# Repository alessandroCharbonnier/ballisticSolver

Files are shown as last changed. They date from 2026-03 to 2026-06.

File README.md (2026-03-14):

# Ballistic Sentinel

A live ballistic calculator for long-range shooting, built on the ESP32-WROOM-32 platform.
The complete C++ ballistic engine is a from-scratch rewrite of [py_ballisticcalc](../bin/py_ballisticcalc),
validated to within 0.3% of the Python reference across 87 scenarios and 1850 trajectory points.

## Features

- **Pure C++ ballistic engine** — header-only library with adaptive RK45 Dormand-Prince integration (float inner loop on ESP32 hardware FPU, double position accumulation), PCHIP interpolation,
  CIPM-2007 atmosphere model, spin drift (Litz formula), Miller stability, Coriolis-ready (disabled pending magnetometer calibration)
- **All 9 standard drag tables**: G1, G7, G2, G5, G6, G8, GI, GS, RA4
- **Multi-BC support** — velocity-stepped ballistic coefficients
- **Four operating modes**:
  - **Live** — dial distance with a combination-lock style 4-digit display (yards)
  - **Staged** — pre-programmed target stages (PRS-style matches, up to 20)
  - **Sensor View** — real-time display of all sensor readings
  - **Digital Level** — full-screen cant readout with graphical bubble level, "LEVEL" indicator + display inversion when within sensitivity threshold, directional tilt hints when off-level
- **Real-time sensors** — BME280 (temperature/pressure/humidity), QMC5883P (compass heading), MPU6050 (cant/roll detection)
- **Calypso ultrasonic anemometer** — NMEA 0183 wind input (prepared, UART2)
- **Cant detection** — MPU6050 accelerometer with auto-calibration, visual cant slider, display auto-invert when level
- **SH1106 1.3" OLED** — 128×64 display with header, distance, corrections, sensor bar, scrolling menu with arrow indicators
- **5-way navigation button** — debounced with double-press, long-press (deep sleep), and auto-repeat
- **WiFi Access Point** — configure rifle/stages via a dark-themed web UI with captive portal
- **Persistent storage** — NVS for rifle config, stage definitions, and cant calibration
- **Power management** — auto-dim after 2 min inactivity (~80% brightness reduction), accelerometer-based auto deep-sleep after 10 min with no motion, ESP32 light sleep between sensor intervals, event-driven ballistic recalculation (on distance change only), BME280 forced mode, compass ODR reduced to 10 Hz, WiFi modem sleep when AP active
- **Battery monitoring** — LiPo voltage via ADC1 (GPIO36) with voltage divider, piecewise-linear discharge curve, battery icon in OLED header on all screens
- **Unit preferences** — configurable imperial/metric units for distance, velocity, weight, length, temperature, and pressure

## Hardware

### Bill of Materials

| Component | Part | Notes |
|---|---|---|
| MCU | ESP32-WROOM-32 (classic) | 520KB SRAM, 4MB Flash |
| Display | 1.3" OLED SH1106 I2C | 128×64, addr 0x3C |
| Env sensor | BME280 | Temp/press/humidity, addr 0x76 |
| Compass | QMC5883P (GY-271 module) | 3-axis magnetometer, addr 0x2C |
| Accelerometer | MPU6050 | Cant/roll detection, addr 0x68 |
| Button | 5-way digital navigation | One GPIO per direction + center |
| Wind sensor | Calypso ultrasonic (optional) | NMEA 0183 at 4800 baud |
| LED | On-board ESP32 LED | GPIO 2 |
| Battery | 3.7V LiPo (e.g. 2000mAh) | Requires 2× 100kΩ voltage divider |
| Resistors | 2 × 100kΩ | Voltage divider for battery ADC |

### Pin Map

| GPIO | Function | Direction | Notes |
|---|---|---|---|
| **21** | I2C SDA | Bidirectional | Shared bus: OLED + BME280 + QMC5883P + MPU6050 |
| **22** | I2C SCL | Output | 400 kHz Fast-mode |
| **32** | Button UP | Input (pull-up) | Active-low |
| **33** | Button DOWN | Input (pull-up) | Active-low |
| **25** | Button LEFT | Input (pull-up) | Active-low |
| **26** | Button RIGHT | Input (pull-up) | Active-low |
| **27** | Button CENTER | Input (pull-up) | Active-low, long-press (5s) = deep sleep, double-press = back |
| **16** | Wind UART2 RX | Input | ← Calypso TX (prepared) |
| **17** | Wind UART2 TX | Output | → Calypso RX (prepared) |
| **2** | Status LED | Output | Solid = WiFi AP active |
| **36** | Battery ADC (VP) | Input | Via 100kΩ+100kΩ voltage divider, ADC1_CH0 |

### I2C Bus Addresses

| Address | Device | Protocol |
|---|---|---|
| 0x3C | SH1106 OLED | U8g2 HW I2C |
| 0x76 | BME280 | Adafruit BME280 |
| 0x2C | QMC5883P | 3-axis magnetometer |
| 0x68 | MPU6050 | Adafruit MPU6050 |

### Wiring Diagram

```
ESP32-WROOM-32
├── GPIO 21 (SDA) ──┬── OLED SDA
│                    ├── BME280 SDA
│                    ├── QMC5883P SDA
│                    └── MPU6050 SDA
├── GPIO 22 (SCL) ──┬── OLED SCL
│                    ├── BME280 SCL
│                    ├── QMC5883P SCL
│                    └── MPU6050 SCL
├── GPIO 32 ──── BTN UP
├── GPIO 33 ──── BTN DOWN
├── GPIO 25 ──── BTN LEFT
├── GPIO 26 ──── BTN RIGHT
├── GPIO 27 ──── BTN CENTER
├── GPIO 16 ──── Calypso TX (RX2)
├── GPIO 17 ──── Calypso RX (TX2)
├── GPIO 36 (VP) ── Battery voltage divider mid-point
│                    (Batt+ ─[100kΩ]─ GPIO36 ─[100kΩ]─ GND)
└── GPIO  2 ──── On-board LED
```

## Software Architecture

```
Ballistic Sentinel/
├── lib/ballistic/          # Header-only C++ ballistic library
│   ├── ballistic.h         # Umbrella include
│   ├── constants.h         # Physical constants, unit conversions
│   ├── vector3d.h          # 3D vector math (Vector3 double + Vector3f float)
│   ├── drag_tables.h       # 9 drag tables (G1/G7/G2/G5/G6/G8/GI/GS/RA4)
│   ├── interpolation.h     # PCHIP Fritsch-Carlson spline
│   ├── atmosphere.h        # CIPM-2007 air density model
│   ├── drag_model.h        # Single & multi-BC drag models
│   ├── trajectory.h        # TrajectoryPoint, CorrectionResult
│   ├── engine_rk4.h        # RK45 Dormand-Prince adaptive integrator, Ridder zero-finding
│   └── calculator.h        # High-level API
├── src/                    # ESP32 firmware
│   ├── config.h            # Pin assignments, timing constants
│   ├── display.h/.cpp      # U8g2 SH1106 OLED driver
│   ├── input.h/.cpp        # 5-way button with debounce/repeat
│   ├── sensors.h/.cpp      # BME280 + QMC5883P + MPU6050 polling
│   ├── storage.h/.cpp      # NVS persistent config
│   ├── web_ui.h            # PROGMEM HTML/CSS/JS
│   ├── webserver.h/.cpp    # ESPAsyncWebServer REST API
│   ├── wind.h/.cpp         # Calypso NMEA parser
│   ├── modes.h/.cpp        # Live/Staged/Sensor mode manager
│   └── main.cpp            # Firmware entry point
├── test/
│   ├── test_native/        # Unity C++ unit tests (37 cases)
│   └── test_compare/       # C++ output for Python comparison
└── platformio.ini          # Build configuration
```

### Ballistic Library API

```cpp
#include <ballistic.h>
using namespace ballistic;

Calculator calc;
calc.configure(0.315, DragTableId::G7,  // BC, drag table
               140, 0.264, 1.35,        // weight_gr, diameter_in, length_in
               2710, 1.5, 8.0, 100);    // mv_fps, sight_in, twist_in, zero_yd
calc.setAtmosphere(59.0, 29.92, 0.0);   // temp_F, pressure_inHg, humidity 0-1
calc.setWind(10.0, 90.0);               // speed_fps, direction_deg
calc.solve();                            // find zero elevation

auto corr = calc.correction(800);        // at 800 yards
// corr.vertical, corr.horizontal, corr.velocity_fps, etc.

auto traj = calc.trajectory(2000, 100);  // max range, step (yards)
for (auto& pt : traj) {
    // pt.distance_ft, pt.height_ft, pt.velocity_fps, pt.mach, ...
}
```

## Building

### Prerequisites

- [PlatformIO CLI](https://platformio.org/install/cli)
- ESP32 board support (auto-installed by PlatformIO)

### Flash Firmware

```bash
cd "Ballistic Sentinel"
pio run -e upesy_wroom -t upload
```

### Run Native Tests

```bash
cd "Ballistic Sentinel"
pio test -e native
```

Expected: **37/37 PASS**

### Run Comparison Tests

Requires `py_ballisticcalc` installed in a Python environment and `g++` in PATH:

```bash
cd <project_root>
python tests/test_compare.py
```

Expected: **1850/1850 PASS** (87 scenarios across 8 calibers, multiple bullets/conditions/features)

## Performance Optimizations

The ESP32 Xtensa LX6 has a hardware single-precision (float) FPU but emulates all double-precision operations in software (~10–50× slower per operation). The ballistic engine is optimized for this constraint:

| Optimization | Description |
|---|---|
| **Float inner loop** | All RK45 velocity/acceleration/k-stage math uses `Vector3f` (float) on hardware FPU. Position accumulation stays in `Vector3` (double) to prevent systematic drift. `sqrtf(sqrtf(x))` replaces `pow(x, 0.25)` for step rejection. |
| **Adaptive RK45 Dormand-Prince** | Replaces fixed-step RK4. Auto-sizes dt from 0.0005s–0.02s based on local truncation error. Large steps in smooth supersonic flight, small steps near transonic. ~3–5× fewer steps than fixed-step at long range. |
| **Atmosphere amortization** | Atmospheric density and speed-of-sound recalculated every 8 steps instead of every step (~87% reduction in CIPM-2007 overhead). |
| **Reciprocal Mach pre-compute** | `1.0/mach_local` computed once per atmosphere refresh, used as multiplication in all 6–7 RK stages per step. |
| **Polynomial barometric formula** | 5th-order Horner's polynomial replaces `std::pow()` in altitude lookup. |
| **Dry-air density fast path** | `cipmDensity()` skips `exp()` and water vapor math when humidity = 0 (the default). |
| **Hinted spline evaluation** | `PchipSpline::evalHinted()` with O(1) amortized lookups instead of O(log n) binary search. |

### Double-Precision Fallback

To revert all integration loops to double precision (for accuracy comparison or debugging), add to `platformio.ini`:

```ini
build_flags =
    -DUSE_DOUBLE_INNER_LOOP
    ...
```

## Web Interface

1. Select **WiFi Toggle** from the main menu to start WiFi AP
2. Connect to **BallisticSentinel** (password: `longrange`)
3. Open `http://192.168.4.1` in any browser (captive portal auto-redirects)
4. Configure rifle parameters, unit preferences, and stage targets
5. Select **WiFi Toggle** again to turn off WiFi

The web UI uses a dark theme (`#0d1117` background) with green accents (`#16c79a`)
and a Courier New monospace font. Includes unit conversion (imperial/metric),
multi-BC configuration, powder sensitivity calculator, cant calibration, and
correction unit selection (MOA, SMOA, MRAD, CM, CLICKS).

### API Endpoints

| Method | Path | Description |
|---|---|---|
| GET | `/` | Web configuration UI |
| GET | `/api/config` | Current rifle + stage config (JSON) |
| POST | `/api/save` | Save rifle + stage config |
| POST | `/api/wifi/off` | Shut down WiFi AP |
| POST | `/api/cant/calibrate` | Start cant auto-calibration |

## Test Coverage

### Native C++ Tests (37 cases)

| Group | Tests | Description |
|---|---|---|
| Constants | 3 | Gravity, std atmosphere, unit conversions |
| Vector3 | 5 | Addition, magnitude, normalize, scalar, dot |
| PCHIP | 2 | Basic interpolation, G7 table accuracy |
| Atmosphere | 5 | Standard, hot, altitude, humidity, unit conversion |
| Drag Model | 2 | Single BC, all 9 tables exist |
| Zero-Finding | 2 | 100 yd, 200 yd zero |
| Trajectory | 3 | Drop increases, velocity decreases, reasonable values |
| Calibers | 4 | .308 G7, .338LM G7, .50BMG G1, 6mm CM G7 |
| Weather | 2 | Hot vs cold, altitude effect |
| Wind | 2 | Crosswind deflection, no-wind spin drift |
| Coriolis | 1 | Effect at 2000 yd |
| Corrections | 2 | MOA/MRAD consistency, click calculations |
| Advanced | 2 | Powder sensitivity, multi-BC |
| Edge Cases | 2 | Zero-distance correction, very close range |

### Python Comparison (1850 points, 87 scenarios)

| Category | Scenarios | Drag | Range | Notes |
|---|---|---|---|---|
| .22 LR brands | 12 | RA4 | 300 yd | SK, Eley Tenex, Eley ELR, Lapua (Center-X, Midas+, LR, SLR, X-Act), RWS R50, CCI SV, Federal GMT |
| .22 LR weather | 5 | RA4 | 300 yd | Hot, cold, altitude, tropical, desert |
| .22 LR wind | 4 | RA4 | 300 yd | 5/10/15 mph cross, quartering |
| .22 LR K22 combo | 1 | RA4 | 300 yd | Hot + crosswind (King of 22LR match day) |
| 6.5 CM bullets | 6 | G7 | 1200 yd | Berger 140 HT, Sierra 140 SMK, Hornady 147 ELD-M + 3 handloads |
| 6.5 CM conditions | 5 | G7 | 1200 yd | Wind, hot, cold, altitude, PRS combined |
| 6mm CM bullets | 4 | G7 | 1200 yd | A-Tip 110, Berger 105 HT, Berger 115 DTAC handload, wind |
| .308 Win bullets | 6 | G7 | 1200 yd | ELD-M 168/178, Berger 185 Jugg, 200gr handload, wind, hot |
| .338 LM (K1M) | 5 | G7 | 1760 yd | ELD-M 285, Berger 300, CE 275, handload, K1M combo |
| .300 PRC (K1M) | 3 | G7 | 1760 yd | A-Tip 250, Berger 230 handload, K1M combo |
| .375 CT (K2M) | 4 | G7 | 3520 yd | 350gr, CE 377, handload, K2M alt+wind |
| .50 BMG (ELR) | 3 | G1 | 2500–3520 yd | Wind, altitude, K2M range |
| Extreme weather | 4 | G7 | 1200–1760 yd | Desert 110°F, mountain 8500 ft, tropical, 7500 ft |
| Wind angles | 5 | G7 | 1200 yd | Head/tail/quartering 45°/135°, 20 mph gust |
| Multi-BC | 6 | G7 | 1200–1760 yd | Velocity-stepped BCs: 6.5 CM, 6mm CM, .308, .338 LM, .300 PRC (with wind/altitude) |
| Powder sensitivity | 6 | G7 | 1200–1760 yd | MV adjusted for temp: cold/hot across 6.5 CM, .308, .338 LM, .300 PRC (with wind/altitude) |
| Original baseline | 8 | G1/G7 | 1500–3000 yd | Original 8 scenarios retained |

**Competition distances**: King of 22LR (300 yd), PRS (1200 yd), King of 1 Mile (1760 yd), King of 2 Miles (3520 yd)

Tolerance: max(0.65"/500yd × distance, 0.3% of absolute value)

## Ideas

**Areas for Improvement**

- Single rifle profile only — serious limitation; PRS shooters switch rifles/loads between stages or seasons
- Wind: manual speed + direction only — oversimplified; no crosswind component decomposition shown to user
- Calypso anemometer: prepared but not connected — the most valuable sensor for the use case is the one that doesn't work yet
- WiFi AP hardcoded credentials — SSID "BallisticSentinel" / password "longrange"; anyone at the range can connect and modify config
- 128×64 monochrome OLED — barely enough pixels for a ballistic HUD; hard to read in bright sun. Acceptable for V1 but limiting
- No shot logging / history — can't review previous shots, stages, or environmental conditions after the fact
- No BLE support — BLE would enable Kestrel data link and phone app integration with far less power than WiFi
- Stage names limited to 16 chars — "Stage 3 - 487yd Barricade" doesn't fit; minor but annoying for match prep
- No truing / velocity validation — no way to true the BC or MV from observed impacts; experienced shooters rely on this heavily
- Latitude set manually via web UI — should auto-populate from phone GPS via the web interface

### Potential Features

#### Ballistic Engine Accuracy

These features address the real-world error budget identified via physics audit and Doppler radar field data (Lapua, Applied Ballistics). Ordered by impact on accuracy.

| Priority | Feature | Impact | Rationale |
|---|---|---|---|
| 1 | **Custom Cd vs Mach drag tables** | Eliminates 1–3+ mil ELR error | G7/G1 are reference-shape approximations. Real bullets have unique drag curves, especially in transonic (Mach 0.9–1.2). Applied Ballistics and Lapua publish Doppler-measured Cd tables. Infrastructure already exists — `PchipSpline` + `DragModel` just need a raw `(Mach, Cd)` constructor that bypasses reference table + BC division. Single highest-impact accuracy improvement possible. |
| 2 | **BC/MV truing from observed impacts** | ~0.3–1 mil at all ranges | Manufacturer BCs can be off 3–5%. MV varies lot-to-lot. Truing adjusts BC and/or MV to match actual observed drop at a known distance. Every serious ballistic app (AB, Kestrel, Strelok) has this. Without it, there's no closed-loop correction. |
| 3 | **Humidity correction to speed of sound** | ~0.05 mil at ELR | Current Mach calculation uses dry-air ideal gas (`sqrt(T_R) × 49.0223`). At 35°C/100% RH, humid air transmits sound ~1.5 m/s faster (0.44% shift). This shifts the transonic boundary and Cd lookup. Low effort — adjust `mach_fps` using water vapor mole fraction already computed by CIPM-2007. |
| 4 | **Aerodynamic jump correction** | ~0.1–0.3 MOA crosswind | When a crosswind acts on a spinning bullet at launch, gyroscopic precession deflects it vertically (up or down depending on twist direction and wind side). Currently ignored. Formula: `AJ ≈ (2 * Clα * ρ * S * d * p) / (2 * m * V) * wind_cross`. Matters at ELR and in strong crosswind. |
| 5 | **Drag table blending / transonic Cd override** | Reduces transonic uncertainty | Allow users to override specific Mach regions of the drag table (e.g., Mach 0.9–1.2) with measured data while keeping G7 elsewhere. Useful for shooters who have partial Doppler data or truing data at transonic distances. |

#### Device & UX Features

| Priority | Feature | Rationale |
|---|---|---|
| 1 | Multiple rifle/load profiles | Hobby shooters often own 3–10 rifles. Switching profiles must be trivial. |
| 2 | Timer in live / staged | Pressing on timer icon starts a countdown, configurable on device or via web app. |
| 2 | GPS integration (phone → device) | Auto-populate latitude, altitude, and azimuth. Removes manual entry errors for Coriolis. |
| 3 | Wind sensor activation (Calypso or Kestrel link) | Measured wind >> guessed wind. Finish the Calypso UART or add Kestrel BLE link. |
| 4 | Azimuth-aware wind decomposition | Show headwind/crosswind components relative to shot direction, not just raw wind angle. Helps shooters visualize the actual correction. |
| 5 | Come-up card / range table export | Many hobbyists tape a card to their stock. Web UI "print range card" is the killer feature for casual use. |
| 6 | Rangefinder BLE integration | Nice-to-have for practice sessions; not needed for competition (Stage mode covers it). |
| 7 | Larger display or e-ink option | Hobbyists shoot in bright sun at benches. E-ink is sunlight-readable and ultra-low power. |
| 8 | Unit conversion calculator | Quick MOA↔MRAD, yards↔meters, fps↔m/s. Hobbyists constantly convert between systems. |
| 9 | BLE phone app | Richer UI for config, real-time mirroring, shot log export, GPS feed — all over low-power BLE. |
| 10 | OTA firmware updates | Hobby users won't flash firmware via USB. WiFi OTA update from web UI is essential for adoption. |
| 11 | Onboard tutorial / help screens | Brief "how to use" on first boot or from menu. Reduces learning curve. |
| 12 | Target angular size / mil-ranging | Calculate target size in mils for rangefinder-less verification or unknown-distance stages (UKD). |
| 13 | Bullet library / presets | Built-in database of common bullets (Sierra, Hornady, Berger) with BC + dimensions pre-filled. Huge time saver. |
| 14 | Shot logging / history | Record shot conditions, corrections, and results for post-session review and trend analysis. |
| 15 | ~~double precision~~ | ✅ Implemented — add `-DUSE_DOUBLE_INNER_LOOP` to `build_flags` in `platformio.ini` to revert all integration loops from float to double precision |

#### Not Worth Implementing (diminishing returns)

| Feature | Why not | Actual impact |
|---|---|---|
| 6DOF model | Requires bullet-specific aerodynamic coefficients (Clα, Cmα, Cnpα, etc.) that shooters don't have. Without them, 6DOF is no better than 3DOF. | ~0.2 mil at 2,700m — dwarfed by transonic drag uncertainty |
| Improved spin drift model | Litz formula is ~10–20% approximate, but spin drift itself is small at PRS ranges. Proper modeling requires 6DOF. | ~0.04 MOA at PRS, ~0.2–0.5 MOA at ELR |
| Altitude-dependent gravity | $g$ varies by ~0.3% from sea level to 10,000 ft. | < 0.01 mil even at ELR |
| Earth curvature correction | Drop-away of ~8" per mile². | ~0.02 mil at 2,000 yd, negligible at PRS |
| Adaptive RK4 step size | Current fixed dt=0.0025s is already accurate to < 0.01 mil. | No measurable improvement |

## Version History

| Version | Date | Changes |
|---|---|---|
| 1.0.0 | 2025-01-XX | Initial release — complete C++ ballistic engine, ESP32 firmware, web UI, 37 native tests, 173-point Python comparison |
| 1.1.0 | 2026-03-13 | Power optimization: event-driven ballistic calc, BME280 forced mode, compass 10 Hz ODR, display 4 fps, split sensor intervals (cant 5 Hz / env 0.5 Hz), ESP32 light sleep, WiFi modem sleep, auto-dim (2 min / 80%), accelerometer-based auto deep-sleep (10 min / 0.43g threshold). Bug fixes: deep-sleep GPIO wakeup loop, wake-from-sleep phantom button press, display inversion persisting on shutdown/wake screens |
| 1.2.0 | 2026-03-13 | New Digital Level mode with full-screen cant readout, graphical bubble level, sensitivity zone marks, "LEVEL" indicator with display inversion, and directional tilt hints. Scrolling main menu with up/down arrow indicators (supports 5+ items without shrinking text). WiFi toggle moved to last menu position |
| 1.3.0 | 2026-03-14 | Expanded comparison test suite: 75 scenarios / 1578 trajectory points (up from 8 / 173). Added .22 LR competition bullets (12 brands, RA4 drag table), centerfire competition & handloaded profiles across 6.5 CM, 6mm CM, .308 Win, .338 LM, .300 PRC, .375 CT, .50 BMG. Weather matrix (hot/cold/altitude/tropical/desert/mountain), wind angles (head/tail/quartering/gust), and competition distance ranges (King of 22LR, PRS, King of 1 Mile, King of 2 Miles) |
| 1.4.0 | 2026-03-14 | Added multi-BC and powder sensitivity comparison scenarios (12 new, 87 total / 1850 points). 6 multi-BC scenarios with velocity-stepped BCs across 5 calibers. 6 powder sensitivity scenarios testing MV adjustment for cold/hot conditions. Both features now validated in C++ vs Python comparison suite |

## License

Internal project — not for distribution.

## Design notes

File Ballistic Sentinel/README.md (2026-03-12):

# Ballistic Sentinel

A live ballistic calculator for long-range shooting, built on the ESP32-WROOM-32 platform.
The complete C++ ballistic engine is a from-scratch rewrite of [py_ballisticcalc](../bin/py_ballisticcalc),
validated to within 0.25% of the Python reference across 8 scenarios and 173 trajectory points.

## Features

- **Pure C++ ballistic engine** — header-only library with RK4 integration, PCHIP interpolation,
  CIPM-2007 atmosphere model, full 3D Coriolis, spin drift (Litz formula), Miller stability
- **All 9 standard drag tables**: G1, G7, G2, G5, G6, G8, GI, GS, RA4
- **Multi-BC support** — velocity-stepped ballistic coefficients
- **Two shooting modes**:
  - **Live** — dial distance with a combination-lock style 4-digit display (yards)
  - **Staged** — pre-programmed target stages (PRS-style matches, up to 20)
- **Real-time sensors** — BME280 (temperature/pressure/humidity), QMC5883L (compass heading for Coriolis)
- **Calypso ultrasonic anemometer** — NMEA 0183 wind input (prepared, UART2)
- **SH1106 1.3" OLED** — 128×64 display with header, distance, corrections, sensor bar
- **5-way navigation button** — debounced with long-press and auto-repeat
- **WiFi Access Point** — configure rifle/stages via a dark-themed web UI
- **Persistent storage** — NVS for rifle config and stage definitions
- **Preset calibers** — 6.5CM, 6CM, 6.5PRC, .308, .300WM, .300PRC, .338LM, .375CT, .50BMG

## Hardware

### Bill of Materials

| Component | Part | Notes |
|---|---|---|
| MCU | ESP32-WROOM-32 (classic) | 520KB SRAM, 4MB Flash |
| Display | 1.3" OLED SH1106 I2C | 128×64, addr 0x3C |
| Env sensor | BME280 | Temp/press/humidity, addr 0x76 |
| Compass | QMC5883L (GY-271 module) | 3-axis magnetometer, addr 0x0D |
| Button | 5-way digital navigation | One GPIO per direction + center |
| Wind sensor | Calypso ultrasonic (optional) | NMEA 0183 at 4800 baud |
| LED | On-board ESP32 LED | GPIO 2 |

### Pin Map

| GPIO | Function | Direction | Notes |
|---|---|---|---|
| **21** | I2C SDA | Bidirectional | Shared bus: OLED + BME280 + QMC5883L |
| **22** | I2C SCL | Output | 400 kHz Fast-mode |
| **32** | Button UP | Input (pull-up) | Active-low |
| **33** | Button DOWN | Input (pull-up) | Active-low |
| **25** | Button LEFT | Input (pull-up) | Active-low |
| **26** | Button RIGHT | Input (pull-up) | Active-low |
| **27** | Button CENTER | Input (pull-up) | Active-low, long-press = WiFi toggle |
| **16** | Wind UART2 RX | Input | ← Calypso TX (prepared) |
| **17** | Wind UART2 TX | Output | → Calypso RX (prepared) |
| **2** | Status LED | Output | Solid = WiFi AP active |

### I2C Bus Addresses

| Address | Device | Protocol |
|---|---|---|
| 0x3C | SH1106 OLED | U8g2 HW I2C |
| 0x76 | BME280 | Adafruit BME280 |
| 0x0D | QMC5883L | QMC5883LCompass |

### Wiring Diagram

```
ESP32-WROOM-32
├── GPIO 21 (SDA) ──┬── OLED SDA
│                    ├── BME280 SDA
│                    └── QMC5883L SDA
├── GPIO 22 (SCL) ──┬── OLED SCL
│                    ├── BME280 SCL
│                    └── QMC5883L SCL
├── GPIO 32 ──── BTN UP
├── GPIO 33 ──── BTN DOWN
├── GPIO 25 ──── BTN LEFT
├── GPIO 26 ──── BTN RIGHT
├── GPIO 27 ──── BTN CENTER
├── GPIO 16 ──── Calypso TX (RX2)
├── GPIO 17 ──── Calypso RX (TX2)
└── GPIO  2 ──── On-board LED
```

## Software Architecture

```
Ballistic Sentinel/
├── lib/ballistic/          # Header-only C++ ballistic library
│   ├── ballistic.h         # Umbrella include
│   ├── constants.h         # Physical constants, unit conversions
│   ├── vector3d.h          # 3D vector math
│   ├── drag_tables.h       # 9 drag tables (G1/G7/G2/G5/G6/G8/GI/GS/RA4)
│   ├── interpolation.h     # PCHIP Fritsch-Carlson spline
│   ├── atmosphere.h        # CIPM-2007 air density model
│   ├── drag_model.h        # Single & multi-BC drag models
│   ├── trajectory.h        # TrajectoryPoint, CorrectionResult
│   ├── engine_rk4.h        # RK4 integration engine, Ridder zero-finding
│   └── calculator.h        # High-level API
├── src/                    # ESP32 firmware
│   ├── config.h            # Pin assignments, timing constants
│   ├── display.h/.cpp      # U8g2 SH1106 OLED driver
│   ├── input.h/.cpp        # 5-way button with debounce/repeat
│   ├── sensors.h/.cpp      # BME280 + QMC5883L polling
│   ├── storage.h/.cpp      # NVS persistent config
│   ├── web_ui.h            # PROGMEM HTML/CSS/JS
│   ├── webserver.h/.cpp    # ESPAsyncWebServer REST API
│   ├── wind.h/.cpp         # Calypso NMEA parser
│   ├── modes.h/.cpp        # Live/Staged mode manager
│   └── main.cpp            # Firmware entry point
├── test/
│   ├── test_native/        # Unity C++ unit tests (37 cases)
│   └── test_compare/       # C++ output for Python comparison
└── platformio.ini          # Build configuration
```

### Ballistic Library API

```cpp
#include <ballistic.h>
using namespace ballistic;

Calculator calc;
calc.configure(0.315, DragTableId::G7,  // BC, drag table
               140, 0.264, 1.35,        // weight_gr, diameter_in, length_in
               2710, 1.5, 8.0, 100);    // mv_fps, sight_in, twist_in, zero_yd
calc.setAtmosphere(59.0, 29.92, 0.0);   // temp_F, pressure_inHg, humidity 0-1
calc.setWind(10.0, 90.0);               // speed_fps, direction_deg
calc.solve();                            // find zero elevation

auto corr = calc.correction(800);        // at 800 yards
// corr.elevation_moa, corr.windage_moa, corr.velocity_fps, etc.

auto traj = calc.trajectory(2000, 100);  // max range, step (yards)
for (auto& pt : traj) {
    // pt.distance_ft, pt.height_ft, pt.velocity_fps, pt.mach, ...
}
```

## Building

### Prerequisites

- [PlatformIO CLI](https://platformio.org/install/cli)
- ESP32 board support (auto-installed by PlatformIO)

### Flash Firmware

```bash
cd "Ballistic Sentinel"
pio run -e upesy_wroom -t upload
```

### Run Native Tests

```bash
cd "Ballistic Sentinel"
pio test -e native
```

Expected: **37/37 PASS**

### Run Comparison Tests

Requires `py_ballisticcalc` installed in a Python environment and `g++` in PATH:

```bash
cd <project_root>
python tests/test_compare.py
```

Expected: **173/173 PASS** (8 scenarios × up to 31 points each)

## Web Interface

1. Long-press CENTER button (3s) to start WiFi AP
2. Connect to **BallisticSentinel** (password: `longrange`)
3. Open `http://192.168.4.1` in any browser
4. Configure rifle parameters and stage targets
5. Long-press CENTER again to turn off WiFi

The web UI uses a dark theme (`#0d1117` background) with green accents (`#16c79a`)
and a monospace font. Includes preset caliber buttons for quick setup.

### API Endpoints

| Method | Path | Description |
|---|---|---|
| GET | `/` | Web configuration UI |
| GET | `/api/config` | Current rifle + stage config (JSON) |
| POST | `/api/save` | Save rifle + stage config |
| POST | `/api/wifi/off` | Shut down WiFi AP |

## Test Coverage

### Native C++ Tests (37 cases)

| Group | Tests | Description |
|---|---|---|
| Constants | 3 | Gravity, std atmosphere, unit conversions |
| Vector3 | 5 | Addition, magnitude, normalize, scalar, dot |
| PCHIP | 2 | Basic interpolation, G7 table accuracy |
| Atmosphere | 5 | Standard, hot, altitude, humidity, unit conversion |
| Drag Model | 2 | Single BC, all 9 tables exist |
| Zero-Finding | 2 | 100 yd, 200 yd zero |
| Trajectory | 3 | Drop increases, velocity decreases, reasonable values |
| Calibers | 4 | .308 G7, .338LM G7, .50BMG G1, 6mm CM G7 |
| Weather | 2 | Hot vs cold, altitude effect |
| Wind | 2 | Crosswind deflection, no-wind spin drift |
| Coriolis | 1 | Effect at 2000 yd |
| Corrections | 2 | MOA/MRAD consistency, click calculations |
| Advanced | 2 | Powder sensitivity, multi-BC |
| Edge Cases | 2 | Zero-distance correction, very close range |

### Python Comparison (173 points, 8 scenarios)

| Scenario | Drag | Range | Conditions |
|---|---|---|---|
| 6.5 Creedmoor | G7 | 2000 yd | Standard atmosphere |
| .308 Winchester | G7 | 1500 yd | 10 mph crosswind |
| .338 Lapua Magnum | G7 | 2500 yd | Hot (100°F), humid |
| .50 BMG | G1 | 2500 yd | Standard atmosphere |
| 6mm Creedmoor | G7 | 1500 yd | Cold (20°F) |
| .300 PRC | G7 | 2000 yd | High altitude (≈5000 ft) |
| .308 Winchester | G1 | 1500 yd | G1 reference |
| .375 CheyTac | G7 | 3000 yd | Extreme long range |

Tolerance: max(0.5"/500yd × distance, 0.25% of absolute value)

## Version History

| Version | Date | Changes |
|---|---|---|
| 1.0.0 | 2025-01-XX | Initial release — complete C++ ballistic engine, ESP32 firmware, web UI, 37 native tests, 173-point Python comparison |

## License

Internal project — not for distribution.

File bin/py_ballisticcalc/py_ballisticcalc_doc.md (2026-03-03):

# py_ballisticcalc Documentation (v2.2.8)

Ballistic trajectory calculator library for Python.  
`pip install py-ballisticcalc`

---

## Table of Contents

1. [Quick Start](#quick-start)
2. [Units System](#units-system)
3. [Core Classes](#core-classes)
   - [DragModel](#dragmodel)
   - [DragModelMultiBC / BCPoint](#dragmodelmultibc--bcpoint)
   - [Ammo](#ammo)
   - [Weapon](#weapon)
   - [Sight](#sight)
   - [Atmo](#atmo)
   - [Wind](#wind)
   - [Shot](#shot)
   - [Calculator](#calculator)
4. [Results](#results)
   - [HitResult](#hitresult)
   - [TrajectoryData](#trajectorydata)
   - [DangerSpace](#dangerspace)
   - [TrajFlag](#trajflag)
5. [Unit Reference](#unit-reference)
   - [Distance](#distance)
   - [Velocity](#velocity)
   - [Angular](#angular)
   - [Weight](#weight)
   - [Temperature](#temperature)
   - [Pressure](#pressure)
   - [Energy](#energy)
6. [PreferredUnits](#preferredunits)
7. [Integration Engines](#integration-engines)
8. [Utility Functions](#utility-functions)

---

## Quick Start

```python
from py_ballisticcalc import *
from py_ballisticcalc.unit import *

# 1. Define drag model
dm = DragModel(0.223, TableG7, Weight(175, Weight.Grain), Distance(0.308, Distance.Inch))

# 2. Define ammo
ammo = Ammo(dm, Velocity(2700, Velocity.FPS))

# 3. Define atmosphere
atmo = Atmo(
    altitude=Distance(0, Distance.Foot),
    pressure=Pressure(29.92, Pressure.InHg),
    temperature=Temperature(59, Temperature.Fahrenheit),
    humidity=0.5
)

# 4. Define weapon
weapon = Weapon(sight_height=Distance(1.5, Distance.Inch), twist=Distance(10, Distance.Inch))

# 5. Define wind
wind = [Wind(Velocity(5, Velocity.MPS), Angular(90, Angular.Degree))]

# 6. Build shot and calculate
shot = Shot(weapon=weapon, ammo=ammo, atmo=atmo, winds=wind)
calc = Calculator()
calc.set_weapon_zero(shot, Distance(100, Distance.Yard))

results = calc.fire(shot,
                    trajectory_range=Distance(1000, Distance.Yard),
                    trajectory_step=Distance(100, Distance.Yard))

# 7. Read results
for p in results:
    print(p.distance >> Distance.Yard,
          p.height >> Distance.Inch,
          p.drop_angle >> Angular.MRad,
          p.windage >> Distance.Inch,
          p.velocity >> Velocity.FPS)
```

---

## Units System

All measurement values are wrapped in typed dimension classes. Each class stores values internally in a **raw unit** and converts on demand.

### Creating a value

```python
d = Distance(100, Distance.Meter)      # constructor
d = Distance.Meter(100)                # not available for all — use constructor form
```

### Reading a value

```python
# >> operator (get_in shorthand)
meters = d >> Distance.Meter           # returns float

# .get_in() method
yards = d.get_in(Distance.Yard)        # returns float

# .convert() — returns new object in different units
d2 = d.convert(Distance.Yard)          # Distance object in yards

# << operator — returns new object without mutating
d3 = d << Distance.Foot                # new Distance in feet, d unchanged
```

### Properties

| Property | Description |
|---|---|
| `.raw_value` | Internal value in the dimension's base unit |
| `.unit_value`| Value in the units it was created with |
| `.units` | The Unit enum it was created with |

### Arithmetic

Unit objects support `+`, `-`, `*`, `/` with numbers and same-dimension objects.  
Dividing two same-dimension objects returns a `float` ratio.  
**Temperature** only supports `+` and `-` (clamped at absolute zero).

---

## Core Classes

### DragModel

Aerodynamic drag model for a projectile.

```python
DragModel(
    bc: float,                    # Ballistic coefficient
    drag_table: list,             # Standard table (TableG1, TableG7, TableRA4, etc.)
    weight: float | Weight = 0,   # Bullet weight (grains) — needed for spin drift
    diameter: float | Distance = 0, # Bullet diameter (inches) — needed for spin drift
    length: float | Distance = 0   # Bullet length (inches) — needed for spin drift
)
```

**Available drag tables:** `TableG1`, `TableG2`, `TableG5`, `TableG6`, `TableG7`, `TableG8`, `TableGI`, `TableGS`, `TableRA4`

Use `get_drag_tables_names()` to list them all at runtime.

**Attributes:**
- `BC` — Ballistic coefficient
- `drag_table` — List of `DragDataPoint(Mach, CD)` pairs
- `weight`, `diameter`, `length` — Projectile dimensions
- `sectional_density` — Calculated lb/in²
- `form_factor` — Calculated dimensionless form factor

**Custom drag table:**
```python
dm = DragModel(1, [DragDataPoint(1, 0.3)])  # Constant Cd = 0.3
```

---

### DragModelMultiBC / BCPoint

Create a drag model from multiple BCs at different velocities. The library interpolates between them.

```python
DragModelMultiBC(
    bc_points: list[BCPoint],
    drag_table: list,
    weight: float | Weight = 0,
    diameter: float | Distance = 0,
    length: float | Distance = 0
) -> DragModel
```

**BCPoint:**
```python
BCPoint(BC: float, Mach: float | None = None, V: float | Velocity | None = None)
```
Specify **either** `Mach` or `V`, not both. Points are auto-sorted by Mach number.

**Example:**
```python
dm = DragModelMultiBC(
    bc_points=[
        BCPoint(BC=0.22, V=Velocity(2500, Velocity.FPS)),
        BCPoint(BC=0.21, V=Velocity(1500, Velocity.FPS)),
    ],
    drag_table=TableG7,
    weight=Weight(175, Weight.Grain),
    diameter=Distance(0.308, Distance.Inch),
)
```

---

### Ammo

Ammunition configuration.

```python
Ammo(
    dm: DragModel,
    mv: float | Velocity,                     # Muzzle velocity
    powder_temp: float | Temperature = None,   # Baseline powder temp (default 15°C)
    temp_modifier: float = 0,                  # Velocity change % per 15°C
    use_powder_sensitivity: bool = False        # Enable auto velocity adjustment
)
```

**Methods:**

| Method | Description |
|---|---|
| `calc_powder_sens(other_velocity, other_temperature)` | Calculate temp sensitivity from two data points. Sets `temp_modifier`. Returns the modifier. |
| `get_velocity_for_temp(current_temp)` | Get temperature-adjusted muzzle velocity. Returns baseline velocity if `use_powder_sensitivity=False`. |

**Powder sensitivity example:**
```python
ammo = Ammo(dm, Velocity(815, Velocity.MPS),
            powder_temp=Temperature(15, Temperature.Celsius),
            use_powder_sensitivity=True)
ammo.calc_powder_sens(Velocity(830, Velocity.MPS), Temperature(30, Temperature.Celsius))
cold_vel = ammo.get_velocity_for_temp(Temperature(-10, Temperature.Celsius))
```

---

### Weapon

Weapon/sight configuration.

```python
Weapon(
    sight_height: float | Distance = None,     # Sight above bore (at muzzle)
    twist: float | Distance = None,            # Barrel twist (+ = right-hand)
    zero_elevation: float | Angular = None,    # Set by Calculator.set_weapon_zero()
    sight: Sight = None                        # Optional sight configuration
)
```

---

### Sight

Optical sight configuration for click calculations.

```python
Sight(
    focal_plane: Literal['FFP', 'SFP', 'LWIR'] = 'FFP',
    scale_factor: float | Distance = None,     # Required for SFP
    h_click_size: float | Angular = None,      # Horizontal click size
    v_click_size: float | Angular = None       # Vertical click size
)
```

**Methods:**

| Method | Description |
|---|---|
| `get_adjustment(target_distance, drop_angle, windage_angle, magnification)` | Returns `SightClicks(vertical, horizontal)` |
| `get_trajectory_adjustment(trajectory_point, magnification)` | Convenience wrapper using a `TrajectoryData` point |

**SightClicks** is a named tuple: `SightClicks(vertical: float, horizontal: float)`

**Example:**
```python
weapon = Weapon(
    sight_height=Distance(1.5, Distance.Inch),
    twist=Distance(10, Distance.Inch),
    sight=Sight('FFP', h_click_size=Angular(0.1, Angular.MRad),
                       v_click_size=Angular(0.1, Angular.MRad))
)
# After calculating trajectory:
clicks = weapon.sight.get_trajectory_adjustment(results[5], magnification=10)
print(f"Up: {clicks.vertical}, Right: {clicks.horizontal}")
```

---

### Atmo

Atmospheric conditions.

```python
Atmo(
    altitude: float | Distance = None,         # Default: 0
    pressure: float | Pressure = None,         # Station pressure (default: std for altitude)
    temperature: float | Temperature = None,   # Default: std for altitude
    humidity: float = 0.0,                     # 0–1 fraction or 0–100 percent
    powder_t: float | Temperature = None       # Powder temp (default: ambient)
)
```

**Properties:** `altitude`, `pressure`, `temperature`, `humidity`, `powder_temp`, `density_ratio`, `mach`, `density_metric` (kg/m³), `density_imperial` (lb/ft³)

**Static methods:**

| Method | Description |
|---|---|
| `Atmo.icao(altitude, temperature, humidity)` | Standard ICAO atmosphere at altitude |
| `Atmo.standard(...)` | Alias for `icao()` |
| `Atmo.standard_pressure(altitude)` | ICAO standard pressure at altitude |
| `Atmo.standard_temperature(altitude)` | ICAO standard temperature at altitude |
| `Atmo.machC(celsius)` | Speed of sound (m/s) at given °C |
| `Atmo.machF(fahrenheit)` | Speed of sound (fps) at given °F |
| `Atmo.machK(kelvin)` | Speed of sound (m/s) at given K |
| `Atmo.calculate_air_density(t, p_hpa, humidity)` | Air density in kg/m³ (CIPM-2007) |

**Instance methods:**

| Method | Description |
|---|---|
| `get_density_and_mach_for_altitude(altitude_ft)` | Returns `(density_ratio, mach_fps)` at altitude |
| `pressure_at_altitude(altitude_ft)` | Pressure (hPa) at altitude |
| `temperature_at_altitude(altitude_ft)` | Temperature (°C) at altitude |

---

### Wind

Wind conditions for a section of the trajectory.

```python
Wind(
    velocity: float | Velocity = None,
    direction_from: float | Angular = None,   # 0=tail, 90=left-to-right
    until_distance: float | Distance = None,  # Range this wind applies to
    *, max_distance_feet: float = 1e8
)
```

**Multiple wind zones** — list sorted by until_distance:
```python
winds = [
    Wind(Velocity(3, Velocity.MPS), Angular(90, Angular.Degree),
         until_distance=Distance(300, Distance.Meter)),
    Wind(Velocity(5, Velocity.MPS), Angular(45, Angular.Degree)),  # rest of range
]
```

---

### Shot

Combines everything into a single calculation input.

```python
Shot(
    *, 
    ammo: Ammo,
    atmo: Atmo = None,                        # Default: standard ICAO
    weapon: Weapon = None,                     # Default: zero sight height
    winds: Sequence[Wind] = None,              # Default: no wind
    look_angle: float | Angular = None,        # Sight-line angle from horizontal
    relative_angle: float | Angular = None,    # Hold-over adjustment added to zero_elevation
    cant_angle: float | Angular = None,        # Gun tilt from vertical
    azimuth: float = None,                     # Bearing 0=N, 90=E (for Coriolis)
    latitude: float = None                     # Latitude in degrees (for Coriolis)
)
```

**Properties:**
- `barrel_elevation` = `look_angle + cos(cant_angle) * zero_elevation + relative_angle`
- `barrel_azimuth` — horizontal angle from cant
- `slant_angle` — synonym for `look_angle`
- `winds` — sorted by `until_distance`

---

### Calculator

Main interface. Thread-safe; creates isolated engine instances per method call.

```python
Calculator(
    *, 
    config: Any = None,         # Engine configuration dict
    engine: str | Engine = None  # Integration engine (default: RK4)
)
```

**Methods:**

| Method | Signature | Description |
|---|---|---|
| `set_weapon_zero` | `(shot, zero_distance) -> Angular` | Sets `shot.weapon.zero_elevation` to hit at `zero_distance`. Returns the elevation angle. |
| `barrel_elevation_for_target` | `(shot, target_distance) -> Angular` | Calculate barrel elevation to hit target (does not modify weapon). |
| `fire` | `(shot, trajectory_range, trajectory_step=None, ...) -> HitResult` | Compute full trajectory. |

**`fire()` parameters:**

| Parameter | Type | Default | Description |
|---|---|---|---|
| `shot` | Shot | required | Shot configuration |
| `trajectory_range` | Distance | required | Maximum range to compute |
| `trajectory_step` | Distance | `trajectory_range` | Step between recorded points |
| `dense_output` | bool | False | Store base data for arbitrary interpolation |
| `time_step` | float | 0.0 | Min time between recorded points (seconds) |
| `flags` | TrajFlag | NONE | Request special trajectory points |
| `raise_range_error` | bool | True | Raise error if out of range |

**Context manager support:**
```python
with Calculator(engine=RK4IntegrationEngine) as calc:
    result = calc.fire(shot, Distance(1000, Distance.Meter))
```

---

## Results

### HitResult

Returned by `Calculator.fire()`. Iterable and indexable.

```python
results = calc.fire(shot, Distance(1000, Distance.Meter), Distance(100, Distance.Meter))
len(results)        # number of trajectory points
results[5]          # 6th TrajectoryData point
for p in results:   # iterate all points
    ...
```

**Methods:**

| Method | Description |
|---|---|
| `get_at(key_attribute, value)` | Interpolate trajectory at any attribute value. E.g. `get_at('distance', Distance(550, Distance.Meter))` |
| `flag(TrajFlag)` | Get first point with specific flag |
| `zeros()` | Get all zero-crossing points (requires `dense_output=True` or `flags=TrajFlag.ZERO`) |
| `danger_space(at_range, target_height)` | Calculate danger space at distance |
| `dataframe(formatted=False)` | Return `pandas.DataFrame` (requires pandas) |
| `plot(look_angle=None)` | Plot trajectory (requires matplotlib) |

---

### TrajectoryData

Named tuple for one trajectory point.

| Field | Type | Description |
|---|---|---|
| `time` | float | Flight time (seconds) |
| `distance` | Distance | Down-range (x-axis) |
| `velocity` | Velocity | Scalar velocity (magnitude) |
| `mach` | float | Velocity in Mach |
| `height` | Distance | Vertical position (y-axis) relative to sight line |
| `slant_height` | Distance | Distance orthogonal to sight line |
| `drop_angle` | Angular | Slant height as angular correction |
| `windage` | Distance | Lateral deflection (z-axis) |
| `windage_angle` | Angular | Windage as angular correction |
| `slant_distance` | Distance | Distance along sight line closest to this point |
| `angle` | Angular | Angle of velocity vector relative to x-axis |
| `density_ratio` | float | Local air density / standard density |
| `drag` | float | Standard drag factor at this point |
| `energy` | Energy | Kinetic energy |
| `ogw` | Weight | Optimal game weight |
| `flag` | TrajFlag | Row type flag |

**Aliases:**
- `x` → `distance`, `y` → `height`, `z` → `windage`
- `target_drop` → `slant_height`
- `drop_adj` (deprecated) → `drop_angle`
- `windage_adj` (deprecated) → `windage_angle`
- `look_distance()` → `slant_distance`

**Extracting values:**
```python
p = results[5]
drop_cm  = p.height >> Distance.Centimeter
drop_mrad = p.drop_angle >> Angular.MRad
wind_cm  = p.windage >> Distance.Centimeter
wind_mrad = p.windage_angle >> Angular.MRad
vel_mps  = p.velocity >> Velocity.MPS
energy_j = p.energy >> Energy.Joule
```

**Static methods:**
- `calculate_energy(bullet_weight_gr, velocity_fps)` → ft·lbf
- `calculate_ogw(bullet_weight_gr, velocity_fps)` → pounds
- `get_correction(distance_ft, offset_ft)` → radians
- `interpolate(key_attribute, value, p0, p1, p2, flag, method)` → interpolated point

---

### DangerSpace

How much ranging error you can tolerate while still hitting a target of given height.

```python
ds = results.danger_space(
    at_range=Distance(500, Distance.Meter),
    target_height=Distance(50, Distance.Centimeter)
)
# ds.begin   → TrajectoryData at start of danger space
# ds.end     → TrajectoryData at end of danger space
# ds.at_range → TrajectoryData at target distance
# ds.target_height → Distance
# ds.look_angle → Angular
```

---

### TrajFlag

Bitwise flags for marking special trajectory points.

| Flag | Value | Description |
|---|---|---|
| `NONE` | 0 | Standard point |
| `ZERO_UP` | 1 | Upward zero crossing |
| `ZERO_DOWN` | 2 | Downward zero crossing |
| `ZERO` | 3 | Any zero crossing (UP \| DOWN) |
| `MACH` | 4 | Mach 1 transition |
| `RANGE` | 8 | User-requested step point |
| `APEX` | 16 | Maximum height |
| `ALL` | 31 | All of the above |
| `MRT` | 32 | Mid-range trajectory / max ordinate |

**Usage:**
```python
results = calc.fire(shot, Distance(1000, Distance.Meter),
                    flags=TrajFlag.ZERO | TrajFlag.APEX | TrajFlag.MACH)
apex = results.flag(TrajFlag.APEX)
```

---

## Unit Reference

### Distance

Raw unit: **inches**

| Constant | Name |
|---|---|
| `Distance.Inch` | inch |
| `Distance.Foot` / `Distance.Feet` | foot |
| `Distance.Yard` | yard |
| `Distance.Mile` | mile |
| `Distance.NauticalMile` | nautical mile |
| `Distance.Millimeter` | millimeter |
| `Distance.Centimeter` | centimeter |
| `Distance.Meter` | meter |
| `Distance.Kilometer` | kilometer |
| `Distance.Line` | line |

### Velocity

Raw unit: **meters per second**

| Constant | Name |
|---|---|
| `Velocity.MPS` | m/s |
| `Velocity.FPS` | ft/s |
| `Velocity.KMH` | km/h |
| `Velocity.MPH` | mph |
| `Velocity.KT` | knot |

### Angular

Raw unit: **radians**  
Angles are normalized to (-π, π].

| Constant | Name |
|---|---|
| `Angular.Radian` | radian |
| `Angular.Degree` | degree |
| `Angular.MOA` | minute of angle |
| `Angular.MRad` | milliradian |
| `Angular.Mil` | NATO mil |
| `Angular.Thousandth` | thousandth |
| `Angular.InchesPer100Yd` | inch/100yd |
| `Angular.CmPer100m` | cm/100m |
| `Angular.OClock` | hour (clock position) |

### Weight

Raw unit: **grains**

| Constant | Name |
|---|---|
| `Weight.Grain` | grain |
| `Weight.Gram` | gram |
| `Weight.Kilogram` | kilogram |
| `Weight.Ounce` | ounce |
| `Weight.Pound` | pound |
| `Weight.Newton` | newton |

### Temperature

Raw unit: **Fahrenheit**  
Only supports `+` and `-`. Clamped at absolute zero.

| Constant | Name |
|---|---|
| `Temperature.Fahrenheit` | fahrenheit |
| `Temperature.Celsius` | celsius |
| `Temperature.Kelvin` | kelvin |
| `Temperature.Rankin` | rankin |

### Pressure

Raw unit: **mmHg**

| Constant | Name |
|---|---|
| `Pressure.MmHg` | mmHg |
| `Pressure.InHg` | inHg |
| `Pressure.Bar` | bar |
| `Pressure.hPa` | hPa (mbar) |
| `Pressure.PSI` | psi |

### Energy

Raw unit: **foot-pounds**

| Constant | Name |
|---|---|
| `Energy.FootPound` | foot-pound |
| `Energy.Joule` | joule |

---

## PreferredUnits

Global defaults for display/creation when units aren't specified explicitly.

```python
PreferredUnits.set(
    distance='meter',
    velocity='mps',
    temperature='celsius',
    angular='degree',
    adjustment='mil',
    pressure='hPa',
    drop='centimeter',
    weight='gram'
)
```

**All configurable fields:**
`angular`, `distance`, `velocity`, `pressure`, `temperature`, `diameter`, `length`, `weight`, `adjustment`, `drop`, `energy`, `ogw`, `sight_height`, `target_height`, `twist`, `time`

**Reset:** `PreferredUnits.restore_defaults()`

**Convenience loaders:**
```python
from py_ballisticcalc import loadMetricUnits, loadImperialUnits, loadMixedUnits
loadMetricUnits()     # Sets all to metric
loadImperialUnits()   # Sets all to imperial (default)
loadMixedUnits()      # Mix of both
```

---

## Integration Engines

The `Calculator` accepts different numerical integration engines.

| Engine | Description |
|---|---|
| `RK4IntegrationEngine` | 4th-order Runge-Kutta **(default)** |
| `EulerIntegrationEngine` | Simple Euler method (faster, less accurate) |
| `VelocityVerletIntegrationEngine` | Velocity Verlet (symplectic) |
| `SciPyIntegrationEngine` | SciPy-based (requires `scipy`) |

**Usage:**
```python
calc = Calculator(engine=EulerIntegrationEngine)
```

**Engine methods** (also accessible via Calculator delegation):

| Method | Description |
|---|---|
| `integrate(shot, max_range, ...)` | Low-level trajectory integration |
| `zero_angle(shot, distance)` | Find barrel elevation for zero |
| `find_zero_angle(shot, distance, lofted=False)` | Find zero angle (supports lofted trajectories) |
| `find_apex(shot)` | Find trajectory apex point |
| `find_max_range(shot, angle_bracket_deg)` | Find maximum range and optimal launch angle |
| `get_calc_step()` | Get integration step size |

---

## Utility Functions

| Function | Description |
|---|---|
| `get_drag_tables_names()` | List all available drag table names |
| `loadMetricUnits()` | Set PreferredUnits to metric |
| `loadImperialUnits()` | Set PreferredUnits to imperial |
| `loadMixedUnits()` | Set PreferredUnits to mixed |
| `enable_file_logging(filename='debug.log')` | Enable DEBUG-level file logging |
| `disable_file_logging()` | Disable file logging |

---

## Exceptions

| Exception | Description |
|---|---|
| `ZeroFindingError` | Failed to find zero elevation |
| `RangeError` | Trajectory didn't reach requested range |
| `OutOfRangeError` | Value out of valid range |
| `InterceptionError` | Interception calculation failed |
| `SolverRuntimeError` | Engine runtime error |
| `UnitConversionError` | Incompatible unit conversion |
| `UnitTypeError` | Wrong unit type |
| `UnitAliasError` | Invalid unit alias string |

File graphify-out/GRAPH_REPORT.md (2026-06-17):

# Graph Report - .  (2026-06-17)

## Corpus Check
- 65 files · ~88,593 words
- Verdict: corpus is large enough that graph structure adds value.

## Summary
- 1311 nodes · 4187 edges · 81 communities (53 shown, 28 thin omitted)
- Extraction: 52% EXTRACTED · 48% INFERRED · 0% AMBIGUOUS · INFERRED: 2017 edges (avg confidence: 0.51)
- Token cost: 0 input · 0 output

## Community Hubs (Navigation)
- [[_COMMUNITY_Integration Engines|Integration Engines]]
- [[_COMMUNITY_Conditions & Munition Models|Conditions & Munition Models]]
- [[_COMMUNITY_Firmware Main Logic|Firmware Main Logic]]
- [[_COMMUNITY_UI & Display Systems|UI & Display Systems]]
- [[_COMMUNITY_Persistent Storage (NVS)|Persistent Storage (NVS)]]
- [[_COMMUNITY_Atmospheric Models (CIPM-2007)|Atmospheric Models (CIPM-2007)]]
- [[_COMMUNITY_Interpolation (PCHIP)|Interpolation (PCHIP)]]
- [[_COMMUNITY_Hardware Sensors (I2C)|Hardware Sensors (I2C)]]
- [[_COMMUNITY_Community 8|Community 8]]
- [[_COMMUNITY_Community 9|Community 9]]
- [[_COMMUNITY_Community 10|Community 10]]
- [[_COMMUNITY_Community 11|Community 11]]
- [[_COMMUNITY_Community 12|Community 12]]
- [[_COMMUNITY_Community 13|Community 13]]
- [[_COMMUNITY_Community 14|Community 14]]
- [[_COMMUNITY_Community 15|Community 15]]
- [[_COMMUNITY_Community 16|Community 16]]
- [[_COMMUNITY_Community 17|Community 17]]
- [[_COMMUNITY_Community 18|Community 18]]
- [[_COMMUNITY_Community 19|Community 19]]
- [[_COMMUNITY_Community 20|Community 20]]
- [[_COMMUNITY_Community 21|Community 21]]
- [[_COMMUNITY_Community 22|Community 22]]
- [[_COMMUNITY_Community 23|Community 23]]
- [[_COMMUNITY_Community 24|Community 24]]
- [[_COMMUNITY_Community 25|Community 25]]
- [[_COMMUNITY_Community 26|Community 26]]
- [[_COMMUNITY_Community 27|Community 27]]
- [[_COMMUNITY_Community 28|Community 28]]
- [[_COMMUNITY_Community 29|Community 29]]
- [[_COMMUNITY_Community 30|Community 30]]
- [[_COMMUNITY_Community 31|Community 31]]
- [[_COMMUNITY_Community 32|Community 32]]
- [[_COMMUNITY_Community 33|Community 33]]
- [[_COMMUNITY_Community 34|Community 34]]
- [[_COMMUNITY_Community 35|Community 35]]
- [[_COMMUNITY_Community 36|Community 36]]
- [[_COMMUNITY_Community 37|Community 37]]
- [[_COMMUNITY_Community 38|Community 38]]
- [[_COMMUNITY_Community 39|Community 39]]
- [[_COMMUNITY_Community 40|Community 40]]
- [[_COMMUNITY_Community 41|Community 41]]
- [[_COMMUNITY_Community 42|Community 42]]
- [[_COMMUNITY_Community 43|Community 43]]
- [[_COMMUNITY_Community 44|Community 44]]
- [[_COMMUNITY_Community 45|Community 45]]
- [[_COMMUNITY_Community 46|Community 46]]
- [[_COMMUNITY_Community 47|Community 47]]
- [[_COMMUNITY_Community 48|Community 48]]
- [[_COMMUNITY_Community 49|Community 49]]
- [[_COMMUNITY_Community 50|Community 50]]
- [[_COMMUNITY_Community 51|Community 51]]
- [[_COMMUNITY_Community 52|Community 52]]
- [[_COMMUNITY_Community 53|Community 53]]
- [[_COMMUNITY_Community 54|Community 54]]
- [[_COMMUNITY_Community 55|Community 55]]
- [[_COMMUNITY_Community 56|Community 56]]
- [[_COMMUNITY_Community 57|Community 57]]
- [[_COMMUNITY_Community 58|Community 58]]
- [[_COMMUNITY_Community 59|Community 59]]
- [[_COMMUNITY_Community 60|Community 60]]
- [[_COMMUNITY_Community 61|Community 61]]
- [[_COMMUNITY_Community 62|Community 62]]
- [[_COMMUNITY_Community 63|Community 63]]
- [[_COMMUNITY_Community 64|Community 64]]
- [[_COMMUNITY_Community 65|Community 65]]
- [[_COMMUNITY_Community 66|Community 66]]
- [[_COMMUNITY_Community 67|Community 67]]
- [[_COMMUNITY_Community 68|Community 68]]
- [[_COMMUNITY_Community 69|Community 69]]
- [[_COMMUNITY_Community 70|Community 70]]
- [[_COMMUNITY_Community 71|Community 71]]
- [[_COMMUNITY_Community 74|Community 74]]
- [[_COMMUNITY_Community 75|Community 75]]
- [[_COMMUNITY_Community 76|Community 76]]
- [[_COMMUNITY_Community 77|Community 77]]
- [[_COMMUNITY_Community 78|Community 78]]
- [[_COMMUNITY_Community 79|Community 79]]
- [[_COMMUNITY_Community 80|Community 80]]

## God Nodes (most connected - your core abstractions)
1. `Distance` - 174 edges
2. `Angular` - 160 edges
3. `HitResult` - 143 edges
4. `TrajFlag` - 139 edges
5. `TrajectoryData` - 133 edges
6. `Vector` - 128 edges
7. `ShotProps` - 115 edges
8. `PreferredUnits` - 103 edges
9. `Shot` - 96 edges
10. `RangeError` - 83 edges

## Surprising Connections (you probably didn't know these)
- `Live Mode` --implemented_by--> `Mode Manager`  [INFERRED]
  README.md → src/modes.cpp
- `Mode Manager` --manages--> `Staged Mode`  [INFERRED]
  src/modes.cpp → README.md
- `compute_multi_bc_trajectory()` --calls--> `DragModelMultiBC()`  [INFERRED]
  test/test_compare.py → bin/py_ballisticcalc/drag_model.py
- `PreferredUnitsMeta` --inherits--> `type`  [EXTRACTED]
  bin/py_ballisticcalc/unit.py → src/web_ui.h
- `Firmware Entry Point` --runs_on--> `ESP32-WROOM-32`  [EXTRACTED]
  src/main.cpp → README.md

## Import Cycles
- None detected.

## Communities (81 total, 28 thin omitted)

### Community 0 - "Integration Engines"
Cohesion: 0.13
Nodes (55): BaseEngineConfigDict, bool, float, HitResult, int, ShotProps, TrajFlag, BaseEngineConfigDict (+47 more)

### Community 1 - "Conditions & Munition Models"
Cohesion: 0.07
Nodes (45): BaseTrajDataAttribute, Angular, bool, str, Vector, Velocity, str, Velocity (+37 more)

### Community 2 - "Firmware Main Logic"
Cohesion: 0.07
Nodes (27): bool, float, Self, NotImplementedType, Protocol, Comparable, GenericDimension, In-place division by a number: `this /= other`.          Returns: (+19 more)

### Community 3 - "UI & Display Systems"
Cohesion: 0.05
Nodes (27): Distance, float, GenericDimension, ShotProps, str, int, Get the human-readable name for a trajectory flag value.          Converts a n, Synonym for .distance. (+19 more)

### Community 4 - "Persistent Storage (NVS)"
Cohesion: 0.11
Nodes (40): Angular, BaseTrajData, bool, Distance, float, HitResult, int, Shot (+32 more)

### Community 5 - "Atmospheric Models (CIPM-2007)"
Cohesion: 0.11
Nodes (40): bool, str, Unit, Any, GenericDimension, GenericDimensionT, BCPoint, Ballistic coefficient point for multi-BC drag models.      Represents a single (+32 more)

### Community 6 - "Interpolation (PCHIP)"
Cohesion: 0.07
Nodes (27): cfg(), namespace, Display(), class, applyConfig(), loop(), updateDisplay(), begin() (+19 more)

### Community 7 - "Hardware Sensors (I2C)"
Cohesion: 0.07
Nodes (16): ASSERT_NEAR(), test_atmosphere_standard(), test_atmosphere_unit_conversions(), test_constants_conversions(), test_correction_clicks(), test_correction_units_consistency(), test_drag_model_single_bc(), test_pchip_basic() (+8 more)

### Community 8 - "Community 8"
Cohesion: 0.07
Nodes (16): CorrectionResult, CorrectionUnit, drawArrowDown(), drawArrowLeft(), drawArrowRight(), drawArrowUp(), drawCantSlider(), drawCorrections() (+8 more)

### Community 9 - "Community 9"
Cohesion: 0.07
Nodes (20): float, Atmo, Altitude relative to sea level., Powder temperature (falls back to ambient when unspecified)., Local speed of sound (Mach 1)., Ratio of local density to standard density (dimensionless)., Relative humidity as fraction [0..1]., Set relative humidity.          Accepts either a fraction [0..1] or percent [0 (+12 more)

### Community 10 - "Community 10"
Cohesion: 0.09
Nodes (20): str, Euler integration engine for ballistic trajectory calculations.  The Euler met, Integration engines for ballistic trajectory calculations.  This package provi, Runge-Kutta 4th order integration engine for ballistic trajectory calculations., Velocity Verlet integration engine for ballistic trajectory calculations.  The, Environmental conditions used by ballistic engines.  What this module provides, Global physical and atmospheric constants for ballistic calculations.  This mo, Ballistics calculator interface and engine loading system.  This module provid (+12 more)

### Community 11 - "Community 11"
Cohesion: 0.09
Nodes (28): bool, DataFrame, HitResult, Angular, Axes, bool, HitResult, int (+20 more)

### Community 12 - "Community 12"
Cohesion: 0.09
Nodes (25): Distance, float, str, DragTableDataType, DragModel, DragModelMultiBC(), linear_interpolation(), make_data_points() (+17 more)

### Community 13 - "Community 13"
Cohesion: 0.13
Nodes (24): Ammo, Atmo, Angular, Vector, Wind, DragDataPoint, PchipPrepared, Coriolis (+16 more)

### Community 14 - "Community 14"
Cohesion: 0.12
Nodes (27): Any, float, HitResult, int, TrajectoryData, Unit, bisect_for_monotonic_condition(), BisectWrapper (+19 more)

### Community 15 - "Community 15"
Cohesion: 0.13
Nodes (24): Angular, Any, bool, ConfigT, Distance, float, HitResult, int (+16 more)

### Community 16 - "Community 16"
Cohesion: 0.09
Nodes (21): ABC, Vector, create_base_engine_config(), Base integration engine for ballistic trajectory calculations.  The module ser, Create BaseEngineConfig from optional dictionary configuration.      This fact, Winds in effect down range.      Currently this class assumes that requests fo, Initialize the _WindSock class.          Args:             winds: A sequence, Return the current cached wind vector.          Raises:             RuntimeEr (+13 more)

### Community 17 - "Community 17"
Cohesion: 0.12
Nodes (18): Angular, Distance, float, ColoredFormatter, Weapon and ammunition configuration for ballistic calculations.  This module p, Initialize a Sight instance with given parameters.          Args:, Calculate SFP reticle steps for target distance and magnification.          Fo, Calculate sight adjustment for target distance and magnification.          Thi (+10 more)

### Community 18 - "Community 18"
Cohesion: 0.16
Nodes (24): Path, compare_rows(), compile_cpp_binary(), compute_multi_bc_trajectory(), compute_powder_sens_trajectory(), compute_python_trajectory(), get_drag_table(), main() (+16 more)

### Community 19 - "Community 19"
Cohesion: 0.16
Nodes (20): BaseException, Angular, Any, bool, ConfigT, Distance, float, HitResult (+12 more)

### Community 20 - "Community 20"
Cohesion: 0.16
Nodes (19): Angular, bool, Distance, float, HitResult, ShotProps, TrajFlag, BaseEngineConfig (+11 more)

### Community 21 - "Community 21"
Cohesion: 0.15
Nodes (18): SensorData, adjustDigit(), begin(), compute(), configureCaclulator(), ButtonState, RifleConfig, StageConfig (+10 more)

### Community 22 - "Community 22"
Cohesion: 0.13
Nodes (18): bool, Distance, Shot, EngineProtocol, Self, Calculator, must_fire(), Wrapper function to resolve RangeError and get HitResult. (+10 more)

### Community 23 - "Community 23"
Cohesion: 0.17
Nodes (20): async, AsyncWebServerRequest, function, id, $(), clickUnitChanged(), disableWifi(), type (+12 more)

### Community 24 - "Community 24"
Cohesion: 0.15
Nodes (19): float, int, _ensure_strictly_increasing(), _hermite_eval(), interpolate_2_pt(), interpolate_3_pt(), pchip_eval(), pchip_prepare() (+11 more)

### Community 25 - "Community 25"
Cohesion: 0.10
Nodes (9): Number, Shortcut for `>> Temperature.Fahrenheit`., In-place numeric addition; clamp at absolute zero., In-place numeric subtraction; clamp at absolute zero., Shortcut for `>> Time.Second`., Shortcut for `>> Velocity.FPS`., Get the numeric value of this measurement in specified units.          Args:, Get the numeric value in the defined units.          Returns:             Num (+1 more)

### Community 26 - "Community 26"
Cohesion: 0.10
Nodes (20): MultiBCScenario, bc_count, bc_pts, diameter_in, humidity, length_in, max_range_yd, mv_fps (+12 more)

### Community 27 - "Community 27"
Cohesion: 0.10
Nodes (20): PowderSensScenario, bc, diameter_in, fps_per_degf, humidity, length_in, max_range_yd, mv_fps (+12 more)

### Community 28 - "Community 28"
Cohesion: 0.11
Nodes (19): DragTableId, Scenario, bc, diameter_in, humidity, length_in, max_range_yd, mv_fps (+11 more)

### Community 29 - "Community 29"
Cohesion: 0.12
Nodes (8): str, Set preferred units from keyword arguments.          Allows bulk configuration, Readable name of the unit of measure., Short symbol of the unit of measure., Find a unit type by searching through a dictionary that maps strings to Units., Parse a unit type from a string representation.          Attempts to parse a s, Human-readable string representation of the unit measurement.          Returns, Detailed string representation for debugging.          Returns:             S

### Community 30 - "Community 30"
Cohesion: 0.21
Nodes (9): Distance, Temperature, Pressure, Initialize an `Atmo` instance.          Args:             altitude: Altitude, Station barometric pressure (not altitude adjusted)., ICAO standard temperature for altitude (valid to ~36,000 ft)., ICAO standard pressure for altitude (valid to ~36,000 ft)., Create a standard ICAO atmosphere at altitude.          Args:             alt (+1 more)

### Community 31 - "Community 31"
Cohesion: 0.15
Nodes (10): int, str, Wind, Optimized wind vector calculator using binary search for O(log n) lookups., Initialize WindSock with optimized data structures for fast lookups., String representation for debugging., Return number of wind zones., ScipyWindSock (+2 more)

### Community 32 - "Community 32"
Cohesion: 0.18
Nodes (9): float, int, Multiply vector by a scalar constant.          Args:             a: Scalar mu, Calculate the dot product (scalar product) of two vectors.          Computes t, Create a unit vector pointing in the same direction.          Returns:, Multiplication operator supporting both scalar and vector multiplication., Right multiplication operator for vector operations.          Enables multipli, In-place multiplication operator for vector operations.          Provides *= o (+1 more)

### Community 33 - "Community 33"
Cohesion: 0.19
Nodes (7): Hashable, IntEnum, Measurable, Enumeration of all supported unit types.      - Angular: Radian, Degree, MOA,, Unit, SupportsFloat, SupportsInt

### Community 34 - "Community 34"
Cohesion: 0.21
Nodes (14): ballistic(), EngineRK4(), evalZero(), recordPoint(), spinDrift(), stabilityCoefficient(), traceToDistance(), traceToPoint() (+6 more)

### Community 35 - "Community 35"
Cohesion: 0.13
Nodes (6): float, Azimuth of the shooting direction in degrees [0, 360).          Should be *geo, Latitude of the shooting location in degrees [-90, 90]., Get the air density and Mach number for a given altitude.          Args:, Litz spin-drift approximation.          Args:             time: Time of fligh, Calculate the Miller stability coefficient.          Returns:             flo

### Community 36 - "Community 36"
Cohesion: 0.24
Nodes (12): atAltitude(), ballistic(), cipmDensity(), cToF(), fToC(), fToK(), hpaToInhg(), inhgToPa() (+4 more)

### Community 37 - "Community 37"
Cohesion: 0.23
Nodes (3): BME280, BME280/BMP280 MicroPython Driver (I2C) Supports both BME280 (temp + humidity +, Returns (temperature_C, pressure_hPa, humidity_%) as a tuple.         Humidity

### Community 38 - "Community 38"
Cohesion: 0.21
Nodes (9): Angular, BaseTrajData, Distance, float, int, str, TrajectoryData, Parameters:         - zero_finding_error: The error magnitude         - iterat (+1 more)

### Community 39 - "Community 39"
Cohesion: 0.21
Nodes (10): BaseEngineConfigDict, Vector, create_scipy_engine_config(), SciPy-based integration engine for high-performance ballistic trajectory calcula, Configuration dataclass for the SciPy integration engine.      This configurat, TypedDict for flexible SciPy integration engine configuration.      This Typed, Initialize the SciPy integration engine with configuration.          Sets up t, # TODO: If _cMinimumVelocity<=0 then: either don't add this event, or always ret (+2 more)

### Community 40 - "Community 40"
Cohesion: 0.27
Nodes (6): EngineFactoryProtocolType, EntryPoint, _EngineLoader, Called by pickle for deserialization.         We manually set the fields and ca, Iterate all available engines in the entry points., Iterate over all available engines in the entry points.

### Community 41 - "Community 41"
Cohesion: 0.22
Nodes (6): ballistic(), ballistic(), ballistic(), namespace, namespace, namespace

### Community 42 - "Community 42"
Cohesion: 0.22
Nodes (4): ballistic(), ballistic(), namespace, namespace

### Community 43 - "Community 43"
Cohesion: 0.22
Nodes (4): Validate that units are compatible with this dimension.          Args:, Create a new instance from a raw value in base units.          Args:, Convert a raw value to the specified units.          Args:             raw_va, Convert a value in specified units to the raw unit.          Args:

### Community 44 - "Community 44"
Cohesion: 0.29
Nodes (4): ballistic(), buildMultiBCSpline(), BCPoint, namespace

### Community 45 - "Community 45"
Cohesion: 0.29
Nodes (4): Add two vectors component-wise.          Args:             b: The other Vecto, Addition operator for vector addition.          Provides intuitive syntax for, Right addition operator for vector addition.          Enables vector addition, In-place addition operator for vector addition.          Provides += operator

### Community 46 - "Community 46"
Cohesion: 0.33
Nodes (5): Any, Event object for SciPy solve_ivp integration with trajectory detection.      T, Call the wrapped event function with time and state parameters.          Args:, SciPyEvent, floating

### Community 47 - "Community 47"
Cohesion: 0.33
Nodes (6): ESP32-WROOM-32, Ballistic Calculator API, Live Mode, Staged Mode, Firmware Entry Point, Mode Manager

### Community 48 - "Community 48"
Cohesion: 0.33
Nodes (3): Subtract one vector from another component-wise.          Args:             b, Subtraction operator for vector subtraction.          Provides intuitive synta, In-place subtraction operator for vector subtraction.          Provides -= ope

### Community 50 - "Community 50"
Cohesion: 0.40
Nodes (4): ballistic(), kZeroVector(), namespace, Vector3

### Community 53 - "Community 53"
Cohesion: 0.70
Nodes (4): main(), runMultiBCScenario(), runPowderSensScenario(), runScenario()

## Knowledge Gaps
- **94 isolated node(s):** `str`, `int`, `ANSIColorCodes`, `str`, `namespace` (+89 more)
  These have ≤1 connection - possible missing edges or undocumented components.
- **28 thin communities (<3 nodes) omitted from report** — run `graphify query` to explore isolated nodes.

## Suggested Questions
_Questions this graph is uniquely positioned to answer:_

- **Why does `PreferredUnitsMeta` connect `Atmospheric Models (CIPM-2007)` to `Community 10`, `Community 23`?**
  _High betweenness centrality (0.085) - this node is a cross-community bridge._
- **Why does `type` connect `Community 23` to `Atmospheric Models (CIPM-2007)`?**
  _High betweenness centrality (0.083) - this node is a cross-community bridge._
- **Why does `Distance` connect `Community 22` to `Integration Engines`, `Conditions & Munition Models`, `Firmware Main Logic`, `UI & Display Systems`, `Persistent Storage (NVS)`, `Atmospheric Models (CIPM-2007)`, `Community 9`, `Community 10`, `Community 11`, `Community 12`, `Community 13`, `Community 14`, `Community 15`, `Community 16`, `Community 17`, `Community 19`, `Community 20`, `Community 30`, `Community 31`, `Community 35`, `Community 38`, `Community 39`, `Community 40`, `Community 46`?**
  _High betweenness centrality (0.077) - this node is a cross-community bridge._
- **Are the 167 inferred relationships involving `Distance` (e.g. with `Ammo` and `Atmo`) actually correct?**
  _`Distance` has 167 INFERRED edges - model-reasoned connections that need verification._
- **Are the 153 inferred relationships involving `Angular` (e.g. with `Ammo` and `Atmo`) actually correct?**
  _`Angular` has 153 INFERRED edges - model-reasoned connections that need verification._
- **Are the 126 inferred relationships involving `HitResult` (e.g. with `BaseException` and `Angular`) actually correct?**
  _`HitResult` has 126 INFERRED edges - model-reasoned connections that need verification._
- **Are the 128 inferred relationships involving `TrajFlag` (e.g. with `Ammo` and `Atmo`) actually correct?**
  _`TrajFlag` has 128 INFERRED edges - model-reasoned connections that need verification._

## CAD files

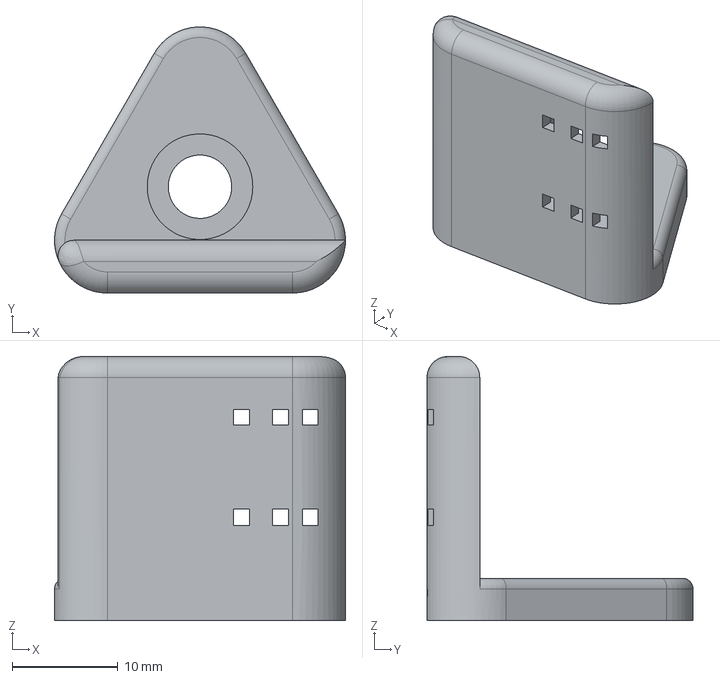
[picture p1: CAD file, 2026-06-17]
CAD/Tikka T1X thumb grip-Body.step
27.5 x 25.2 x 25.0 mm

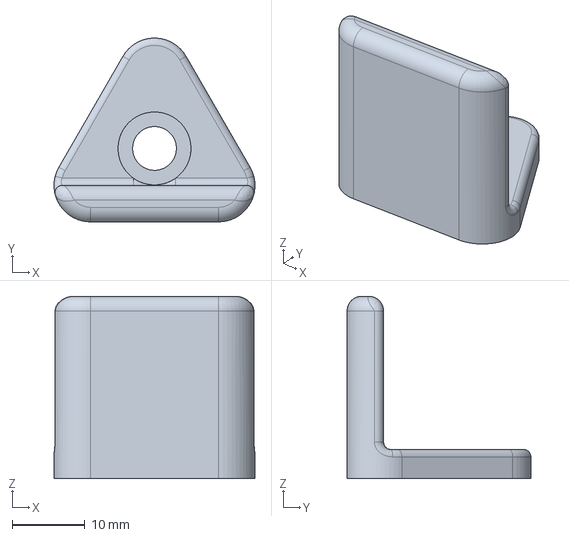
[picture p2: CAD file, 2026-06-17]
CAD/Tikka T1X thumb grip flat.FCStd
27.6 x 25.2 x 25.0 mm

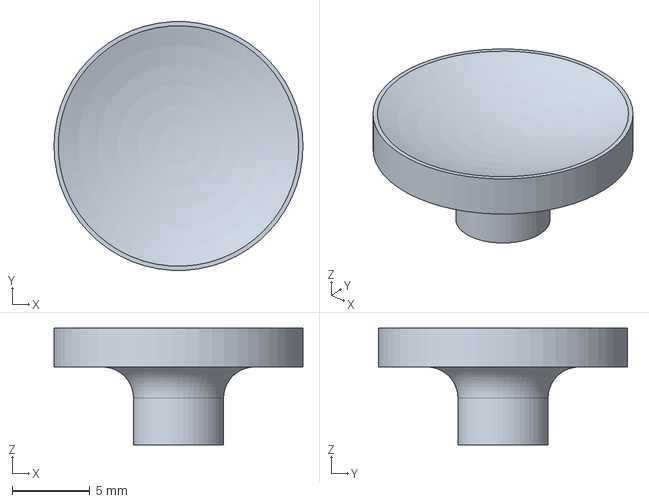
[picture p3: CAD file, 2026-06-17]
CAD/5Axis button cap.FCStd
16.0 x 16.0 x 7.50 mm

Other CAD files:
CAD/Tikka T1X thumb grip flat-Body.step
CAD/Tikka T1X thumb grip.FCStd
CAD/5Axis button cap-Body.step
CAD/Tikka T1X thumb grip flat-Body.3mf
CAD/Tikka T1X thumb grip-Body.3mf

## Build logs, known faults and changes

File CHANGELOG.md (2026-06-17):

# Changelog

All notable changes to this project will be documented in this file.

The format is based on [Keep a Changelog](https://keepachangelog.com/),
and this project adheres to [Semantic Versioning](https://semver.org/).

## [Unreleased]

### Added
- **Magnetometer (compass) calibration** — hard iron offset and soft iron scale correction for QMC5883P. Calibration is triggered from the Sensor View screen: press CENTER to start, rotate the device 360° on a flat surface, press CENTER again to finish. Calibration values (offset X/Y, scale X/Y) are persisted in NVS and reloaded on boot. Fixes incorrect heading readings and non-linear rotation caused by nearby electronics (ESP32, OLED, wires).

### Fixed
- **WiFi cycling crash** — replaced `WiFi.mode(WIFI_OFF)` with `esp_wifi_stop()` in `WebServer_::stop()` to preserve the ESP32 netif layer. `WiFi.mode(WIFI_OFF)` destroys the default AP netif but doesn't fully deregister the netstack callback, causing `netstack cb reg failed with 12308` (`ESP_ERR_INVALID_STATE`) on the next `WiFi.mode(WIFI_AP)`.
- **Web UI `/api/wifi/off` state desync** — `handleWifiOff` now sets a pending flag instead of directly calling `WiFi.softAPdisconnect()`/`WiFi.mode(WIFI_OFF)` from the async handler. Shutdown is deferred to `processDNS()` on the main loop, which calls `stop()` properly. This prevents `active_` from staying stale and avoids blocking `delay()` inside the async web server task.
- **WiFi LED/menu sync** — main loop now syncs `Modes::wifi_on_` and LED state with `WebServer_::isActive()` after each `processDNS()` call, so the menu and LED stay correct when WiFi is shut down from the web UI.

### Changed
- **Performance: float inner loop (ESP32 hardware FPU)** — all three integration methods (`traceToDistance`, `traceToPoint`, `trajectory`) now run velocity, acceleration, and RK45 stages in single-precision `float` (`Vector3f`), leveraging the ESP32 Xtensa LX6 hardware FPU. Position accumulation stays in `double` to prevent systematic drift. Each double multiply/divide on ESP32 was ~10-50× slower than float due to software emulation; with ~50+ float vector ops per RK45 step, this yields a major speedup. `sqrtf(sqrtf(x))` replaces `pow(x, 0.25)` for step rejection scaling (two hardware sqrtf vs software double pow). Float's 7 significant digits give sub-0.01 MOA accuracy per step — well below BC/atmosphere model uncertainty.
- **Performance: adaptive RK45 Dormand-Prince integrator** — replaced fixed-step RK4 (dt=0.0025s, ~1400 steps at 2000m) with adaptive Dormand-Prince RK4(5) using embedded error estimation. Automatically uses large steps (~0.01-0.02s) in smooth supersonic flight and small steps near transonic transition. Reduces step count by ~3-5× for long-range shots while maintaining accuracy via per-step error control (tolerance 1e-6 ft)
- **Performance: atmosphere amortization** — atmospheric density and speed of sound recalculated every 8 steps instead of every step, reducing CIPM density + `sqrt()` overhead by ~87% with negligible error (<0.001% density change over 8 steps)
- **Performance: reciprocal Mach pre-compute** — replaced 4× `speed / mach_local` divisions per step with 4× multiplications by pre-computed `1.0 / mach_local` (updated at atmosphere refresh). Eliminates ~6000 cycles/step on ESP32 software double FPU
- **Performance: fast magnitude** — added `Vector3::fastMagnitude()` using hardware `float` `sqrtf()` + one Newton-Raphson refinement step (~14 digits precision). Replaces `std::sqrt(double)` in inner loop (4× per step), leveraging ESP32 hardware single-precision FPU
- **Performance: polynomial barometric formula** — replaced `std::pow()` in `AtmoPrecomp::atAltitude()` with 5th-order Horner's polynomial (exact to double precision for trajectory altitude ranges), eliminating the most expensive per-step call on ESP32
- **Performance: dry-air density fast path** — `cipmDensity()` skips `std::exp()` and all water vapor calculations when humidity is zero (the default and most common setting)
- **Performance: hinted spline evaluation** — added `PchipSpline::evalHinted()` with O(1) amortized lookups instead of O(log n) binary search, used in all integration loops where Mach changes monotonically
- **Performance: pre-computed loop invariants** — drag coefficient factor, stability coefficient, and atmospheric base values computed once before integration instead of per-step
- **Performance: magnitudeSquared termination** — replaced `magnitude() < threshold` with `magnitudeSquared() < threshold²` in termination checks, eliminating one `sqrt()` per integration step
- **Performance: compiler flags** — added `-fno-math-errno` for ESP32 build, `-O2` for native test builds

### Added
- `Vector3f` single-precision 3D vector type (`vector3d.h`) with hardware `sqrtf()` magnitude, used by float inner loops
- `CoriolisParams::accelerationF()` float-precision overload for inner-loop Coriolis computation
- **87 comparison test scenarios** (up from 75) with 1850 trajectory points
- **6 multi-BC scenarios** — velocity-stepped ballistic coefficients validated across C++ and Python:
  6.5 CM Berger 140 HT, 6.5 CM 147 ELD-M (with wind), .338 LM Berger 300, .300 PRC Berger 230 (altitude),
  6mm CM A-Tip 110, .308 Win Berger 185 (with wind)
- **6 powder sensitivity scenarios** — MV-adjusted-for-temperature validated across C++ and Python:
  6.5 CM 140 ELD-M (cold 20°F + hot 110°F), .308 175 SMK (extreme cold 0°F), .338 LM 300gr (hot desert 115°F),
  6.5 CM 147 ELD-M (cold 15°F + crosswind), .300 PRC 230gr (cold high-altitude 25°F)
- `MultiBCScenario` dataclass and `compute_multi_bc_trajectory()` in Python test suite
- `PowderSensScenario` dataclass and `compute_powder_sens_trajectory()` in Python test suite
- `MultiBCScenario` / `PowderSensScenario` structs and `runMultiBCScenario()` / `runPowderSensScenario()` in C++ test suite
- `.22 LR competition bullet profiles`: SK Rifle Match, SK Long Range, Eley Tenex, Eley ELR (Contact), Lapua Center-X, Lapua Midas+, Lapua Long Range, Lapua Super Long Range, Lapua X-Act, RWS R50, CCI Standard Velocity, Federal Gold Medal Target
- Centerfire competition bullets per caliber: Berger Hybrid Target, Sierra MatchKing, Hornady ELD-M / A-Tip, Cutting Edge MTAC, and others
- Handloaded profiles for 6.5 CM (Berger 153.5 LRHT, 140 ELD-M hot, 147 ELD-M pushed), 6mm CM (Berger 115 DTAC), .308 Win (Berger 200 HT), .338 LM (Berger 300 OTM hot), .375 CT (350gr pushed), .300 PRC (Berger 230 HT)
- Weather condition matrix: standard ICAO, hot (100°F), cold (10°F), altitude (5000 ft), desert (110°F), tropical (90°F/90% RH), mountain (8500 ft cold), very high altitude (7500 ft)
- Wind variation tests: 5/10/15/20 mph crosswind, quartering 45°/135°, headwind, tailwind
- Competition distance ranges: King of 22LR (300 yd), PRS (1200 yd), King of 1 Mile (1760 yd), King of 2 Miles (3520 yd)
- Combined condition scenarios simulating real match days (altitude + wind + temperature)

### Changed
- **Refactored C++ multi-BC drag model** (`buildMultiBCSpline` in `drag_model.h`):
  replaced average-BC normalization with per-Mach form-factor folding (matching
  Python's `DragModelMultiBC`).  At runtime `drag(m) = Cd_ref(m) / BC(m)` —
  exact per-Mach BC instead of an averaged approximation.  Eliminates the
  previous 7-15 fps velocity divergence; multi-BC scenarios now pass at the
  same tight tolerances as single-BC.
- Removed multi-BC tolerance multiplier from test harness; all 1850 points use
  uniform tolerances (drop 0.65", velocity 5 fps, energy 2%).
- **Fixed C++ molar mass constant** (`atmosphere.h` CIPM-2007 density model):
  corrected `Ma` from `28.9635e-3` to `28.96546e-3` kg/mol to match the
  published CIPM-2007 standard and the Python reference.  Eliminates a ~0.007%
  systematic error in air density calculations.
- **Added Coriolis to C++ zero-finder** (`traceToDistance` in `engine_rk4.h`):
  the zero-finding integrator now includes Coriolis acceleration, matching the
  Python engine which uses its full `_integrate()` (with Coriolis) for zeroing.
  Previously the C++ zero-finder omitted Coriolis, causing a small systematic
  bias in the barrel elevation when Coriolis was enabled.
- `run_cpp_binary()` now uses per-scenario step sizes instead of hardcoded 100 yd snap, supporting 25 yd (`.22 LR`), 50 yd (`PRS`), and 100 yd step intervals
- Increased C++ binary execution timeout from 60s to 300s to accommodate 75 scenarios
- Updated README trajectory point count from 173 to ~1500

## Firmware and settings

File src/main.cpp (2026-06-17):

/// @file main.cpp
/// @brief Ballistic Sentinel — entry point.
///
/// Ties together all sub-systems: display, input, sensors, wind, storage,
/// ballistic calculator (modes), and optional WiFi web-server.

#include <Arduino.h>
#include <Wire.h>
#include <esp_sleep.h>
#include <esp_wifi.h>

#include "config.h"
#include "display.h"
#include "input.h"
#include "sensors.h"
#include "storage.h"
#include "wind.h"
#include "webserver.h"
#include "modes.h"

// ═══════════════════════════════════════════════════════════════════════════
//  Globals
// ═══════════════════════════════════════════════════════════════════════════

static Display     g_display;
static Input       g_input;
Sensors            g_sensors;
static WindSensor  g_wind;
Storage            g_storage;
static WebServer_  g_web;
static ModeManager g_modes;

RifleConfig        g_rifle;
StageConfig        g_stages;

/// Set by the web-server REST handler when a new config is POSTed.
volatile bool g_config_changed = false;

// Timing
static uint32_t s_last_env_sensor  = 0;
static uint32_t s_last_cant_sensor = 0;
static uint32_t s_last_display     = 0;
static uint32_t s_last_batt_read   = 0;

// Activity tracking for auto-sleep
static uint32_t s_last_activity    = 0;

static bool     s_display_dirty    = true;
static bool     s_calc_needed      = true;

static constexpr uint32_t DISPLAY_INTERVAL_MS = 1000 / cfg::DISPLAY_FPS;

// ═══════════════════════════════════════════════════════════════════════════
//  Helpers
// ═══════════════════════════════════════════════════════════════════════════

/// Reload config from NVS and push to the mode manager.
static void applyConfig() {
    g_modes.reconfigure(g_rifle, g_stages);
    Serial.println("[main] Config applied");
}

/// Push the latest mode state to the display.
static void updateDisplay() {
    g_display.setAppState(static_cast<uint8_t>(g_modes.appState()));
    g_display.setUnitDistance(g_modes.unitDistance());
    g_display.setUnitTemperature(g_modes.unitTemperature());
    g_display.setUnitPressure(g_modes.unitPressure());

    if (g_modes.appState() == AppState::MAIN_MENU) {
        g_display.setMenuCursor(g_modes.menuCursor());
        g_display.setWifiOn(g_modes.wifiOn());
    } else if (g_modes.appState() == AppState::SENSOR_VIEW) {
        const auto& sd = g_sensors.data();
        const auto& wd = g_wind.data();
        g_display.setSensors(sd.temperature_f, sd.pressure_inhg, sd.humidity_pct);
        g_display.setHeading(sd.heading_deg);
        g_display.setCompassCalibrating(g_sensors.compassCalibrating());
        g_display.setCant(sd.cant_deg);
        g_display.setCantCalibration(g_rifle.cant_offset,
                                      g_rifle.cant_sensitivity);
        g_display.setWind(wd.speed_mph, wd.angle_deg, wd.available);
    } else if (g_modes.appState() == AppState::DIGITAL_LEVEL) {
        const auto& sd = g_sensors.data();
        g_display.setCant(sd.cant_deg);
        g_display.setCantCalibration(g_rifle.cant_offset,
                                      g_rifle.cant_sensitivity);
    } else {
        bool staged = (g_modes.appState() == AppState::STAGE_SHOOTING);
        g_display.setMode(staged, g_modes.stageIndex(), g_modes.stageCount());

        if (staged) {
            g_display.setStageName(g_modes.stageName());
        }

        g_display.setDistance(g_modes.displayDistance());
        g_display.setCorrection(g_modes.result(), g_modes.corrUnit());
        g_display.setLiveDigitCursor(g_modes.digitCursor());

        const auto& sd = g_sensors.data();
        g_display.setSensors(sd.temperature_f, sd.pressure_inhg, sd.humidity_pct);
        g_display.setCant(sd.cant_deg);
        g_display.setCantCalibration(g_rifle.cant_offset,
                                      g_rifle.cant_sensitivity);
    }

    g_display.setWifiActive(g_web.isActive());
    g_display.setBattery(g_sensors.data().battery_pct,
                          g_sensors.data().battery_v);
    g_display.update();
}

// ═══════════════════════════════════════════════════════════════════════════
//  Setup
// ═══════════════════════════════════════════════════════════════════════════

void setup() {
    Serial.begin(115200);
    Serial.println("\n=== Ballistic Sentinel ===");

    // I2C bus
    Wire.begin(cfg::PIN_I2C_SDA, cfg::PIN_I2C_SCL);
    Wire.setClock(cfg::I2C_FREQ_HZ);

    // Sub-system init
    g_display.begin();
    g_input.begin();
    g_sensors.begin();
    g_wind.begin();

    // Load saved config (or use defaults)
    if (!g_storage.load(g_rifle, g_stages)) {
        Serial.println("[main] No saved config — using defaults");
    } else {
        Serial.println("[main] Config loaded from NVS");
    }

    // Init ballistic engine with loaded config
    g_modes.begin(g_rifle, g_stages);

    // Load compass calibration into sensor driver
    if (g_rifle.mag_calibrated) {
        g_sensors.setCompassCalibration(
            g_rifle.mag_offset_x, g_rifle.mag_offset_y,
            g_rifle.mag_scale_x,  g_rifle.mag_scale_y);
        Serial.printf("[main] Compass cal loaded: off=(%.1f,%.1f) scl=(%.3f,%.3f)\n",
                      (double)g_rifle.mag_offset_x, (double)g_rifle.mag_offset_y,
                      (double)g_rifle.mag_scale_x,  (double)g_rifle.mag_scale_y);
    }

    // Initial sensor read + computation
    g_sensors.update();
    g_modes.compute(g_sensors.data(), g_wind.data());

    // LED off (we use it as WiFi indicator)
    pinMode(cfg::PIN_LED, OUTPUT);
    digitalWrite(cfg::PIN_LED, LOW);

    Serial.println("[main] Ready");

    s_last_activity = millis();

    // ── Wake-from-sleep validation ─────────────────────────────────────
    // After deep-sleep wakeup, require CENTER held for 5 s to fully boot.
    // If released early, go straight back to sleep.
    if (esp_sleep_get_wakeup_cause() == ESP_SLEEP_WAKEUP_EXT0) {
        Serial.println("[main] Woke from deep sleep — hold CENTER 5s to confirm");
        const uint32_t wake_hold_ms = cfg::WAKE_HOLD_MS;
        uint32_t hold_start = millis();
        bool confirmed = false;

        while (millis() - hold_start < wake_hold_ms) {
            if (digitalRead(cfg::PIN_BTN_CENTER) != LOW) {
                // Button released too early — go back to sleep
                Serial.println("[main] CENTER released — returning to sleep");
                g_display.clearScreen();
                g_input.configureWakeup();
                esp_deep_sleep_start();
            }
            uint8_t pct = (uint8_t)((millis() - hold_start) * 100 / wake_hold_ms);
            g_display.showWakeProgress(pct);
            delay(50);
        }
        Serial.println("[main] Wake confirmed");

        // Wait for CENTER to be released before entering loop,
        // otherwise poll() sees it as a new press event.
        while (digitalRead(cfg::PIN_BTN_CENTER) == LOW) {
            delay(10);
        }
        delay(cfg::BTN_DEBOUNCE_MS);  // let debounce settle
    }
}

// ═══════════════════════════════════════════════════════════════════════════
//  Loop
// ═══════════════════════════════════════════════════════════════════════════

void loop() {
    uint32_t now = millis();

    // ── Input ──────────────────────────────────────────────────────────────
    ButtonState btn = g_input.poll();

    if (btn.event != ButtonEvent::NONE) {
        static const char* const btn_names[] = {
            "NONE", "UP", "DOWN", "LEFT", "RIGHT", "CENTER"
        };
        static const char* const evt_names[] = {
            "NONE", "PRESS", "DOUBLE", "LONG", "REPEAT"
        };
        Serial.printf("[input] %s %s\n",
            btn_names[static_cast<uint8_t>(btn.id)],
            evt_names[static_cast<uint8_t>(btn.event)]);

        s_last_activity = now;
        s_display_dirty = true;

        // 5s hold CENTER → deep sleep
        if (btn.id == ButtonId::CENTER && btn.event == ButtonEvent::LONG_PRESS) {
            g_display.showShutdown();
            delay(1000);
            g_display.clearScreen();
            // Clear light-sleep wakeup sources before deep sleep
            esp_sleep_disable_wakeup_source(ESP_SLEEP_WAKEUP_GPIO);
            esp_sleep_disable_wakeup_source(ESP_SLEEP_WAKEUP_TIMER);
            g_input.configureWakeup();  // ext0 only
            esp_deep_sleep_start();
        }

        g_modes.handleButton(btn);

        // WiFi toggled from menu
        if (g_modes.wifiToggled()) {
            if (g_modes.wifiOn()) {
                g_web.begin();
            } else {
                g_web.stop();
            }
            digitalWrite(cfg::PIN_LED, g_modes.wifiOn() ? HIGH : LOW);
        }
    }

    // ── Config hot-reload from web server ─────────────────────────────────
    if (g_config_changed) {
        g_config_changed = false;
        g_storage.load(g_rifle, g_stages);   // re-read what webserver saved
        applyConfig();
        s_calc_needed = true;
        s_display_dirty = true;
        s_last_activity = now;
    }

    // ── Wind sensor polling ───────────────────────────────────────────────
    g_wind.poll();

    // ── Captive portal DNS ────────────────────────────────────────────────
    g_web.processDNS();

    // Sync WiFi state — the web UI can shut down WiFi independently
    if (g_modes.wifiOn() != g_web.isActive()) {
        g_modes.setWifiOn(g_web.isActive());
        digitalWrite(cfg::PIN_LED, g_web.isActive() ? HIGH : LOW);
    }

    // ── Cant calibration completion ───────────────────────────────────────
    if (g_sensors.cantCalibrationDone()) {
        g_rifle.cant_offset = g_sensors.cantCalibrationResult();
        g_storage.save(g_rifle, g_stages);
        s_display_dirty = true;
        Serial.printf("[main] Cant calibrated: offset=%.2f\n",
                      (double)g_rifle.cant_offset);
    }

    // ── Compass calibration start/finish (from sensor view) ──────────────
    if (g_modes.compassCalibRequested() && !g_sensors.compassCalibrating()) {
        g_sensors.startCompassCalibration();
        g_modes.setCompassCalActive(true);
        s_display_dirty = true;
    }
    if (g_modes.compassCalibFinishRequested() && g_sensors.compassCalibrating()) {
        g_sensors.finishCompassCalibration();
        g_modes.setCompassCalActive(false);
        s_display_dirty = true;
    }
    if (g_sensors.compassCalibrationDone()) {
        g_rifle.mag_offset_x   = g_sensors.magOffsetX();
        g_rifle.mag_offset_y   = g_sensors.magOffsetY();
        g_rifle.mag_scale_x    = g_sensors.magScaleX();
        g_rifle.mag_scale_y    = g_sensors.magScaleY();
        g_rifle.mag_calibrated = true;
        g_storage.save(g_rifle, g_stages);
        s_display_dirty = true;
        Serial.printf("[main] Compass calibrated & saved\n");
    }

    // ── MPU6050 cant + compass read (5 Hz — fast for live indicators) ────
    if (now - s_last_cant_sensor >= cfg::CANT_SENSOR_INTERVAL_MS) {
        s_last_cant_sensor = now;
        g_sensors.updateCant();
        g_sensors.updateCompass();
        s_display_dirty = true;
    }

    // ── Environmental sensors (BME280 + compass, every 2 s) ──────────────
    if (now - s_last_env_sensor >= cfg::ENV_SENSOR_INTERVAL_MS) {
        s_last_env_sensor = now;
        g_sensors.updateEnvironment();
        s_display_dirty = true;
    }

    // ── Battery voltage (every 10 s) ──────────────────────────────────
    if (now - s_last_batt_read >= cfg::BATT_READ_INTERVAL_MS) {
        s_last_batt_read = now;
        g_sensors.updateBattery();
        s_display_dirty = true;
    }

    // ── Motion-based activity tracking ────────────────────────────────────
    if (g_sensors.motionDetected()) {
        s_last_activity = now;
        Serial.println("[power] Motion detected — activity timer reset");
    }

    // ── Auto-dim after inactivity ─────────────────────────────────────────
    bool should_dim = (now - s_last_activity > cfg::AUTO_DIM_TIMEOUT_MS);
    g_display.setDimmed(should_dim);

    // ── Auto deep-sleep on inactivity (no motion + no button) ─────────────
    if (!g_web.isActive()
        && (now - s_last_activity > cfg::AUTO_SLEEP_TIMEOUT_MS))
    {
        Serial.println("[main] No motion detected — entering deep sleep");
        g_display.showShutdown();
        delay(500);
        g_display.clearScreen();
        // Clear light-sleep wakeup sources before deep sleep
        esp_sleep_disable_wakeup_source(ESP_SLEEP_WAKEUP_GPIO);
        esp_sleep_disable_wakeup_source(ESP_SLEEP_WAKEUP_TIMER);
        g_input.configureWakeup();  // ext0 only
        esp_deep_sleep_start();
    }

    // ── Ballistic calculation (on distance or config change only) ─────────
    if (g_modes.distanceChanged() || g_modes.configChanged() || s_calc_needed) {
        s_calc_needed = false;
        g_modes.compute(g_sensors.data(), g_wind.data());
        s_display_dirty = true;
    }

    // ── Display refresh ──────────────────────────────────────────────────
    if (s_display_dirty && (now - s_last_display >= DISPLAY_INTERVAL_MS)) {
        s_last_display = now;
        s_display_dirty = false;
        updateDisplay();
    }

    // ── Light sleep when idle (skip if WiFi AP is active) ────────────────
    if (!g_web.isActive()) {
        uint32_t next_cant    = s_last_cant_sensor + cfg::CANT_SENSOR_INTERVAL_MS;
        uint32_t next_env     = s_last_env_sensor  + cfg::ENV_SENSOR_INTERVAL_MS;
        uint32_t next_display = s_last_display     + DISPLAY_INTERVAL_MS;
        uint32_t next_wake    = next_cant;
        if (next_env < next_wake) next_wake = next_env;
        if (s_display_dirty && next_display < next_wake) next_wake = next_display;

        int32_t sleep_ms = static_cast<int32_t>(next_wake - now);
        if (sleep_ms > 10) {
            esp_sleep_enable_timer_wakeup(
                static_cast<uint64_t>(sleep_ms) * 1000ULL);
            // Button ISRs will also wake from light sleep
            esp_sleep_enable_gpio_wakeup();
            esp_light_sleep_start();
        }
    }
}

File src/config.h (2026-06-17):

#pragma once
/// @file config.h
/// @brief Hardware pin assignments and system constants for Ballistic Sentinel.
///
/// ESP32-WROOM-32 pin map:
///
///   I2C Bus (shared by OLED, BME280, QMC5883L)
///     SDA  → GPIO 21
///     SCL  → GPIO 22
///
///   5-Way Button (active-low with internal pull-up)
///     UP     → GPIO 32
///     DOWN   → GPIO 33
///     LEFT   → GPIO 25
///     RIGHT  → GPIO 26
///     CENTER → GPIO 27
///
///   Battery ADC (voltage divider: 100kΩ + 100kΩ)
///     ADC  ← GPIO 36 (VP / ADC1_CH0)
///
///   Calypso Ultrasonic Anemometer (UART2, prepared — not yet connected)
///     RX ← GPIO 16
///     TX → GPIO 17
///
///   Status LED (on-board)
///     LED  → GPIO 2

#include <cstdint>

namespace cfg {

// ---------------------------------------------------------------------------
//  I2C
// ---------------------------------------------------------------------------
constexpr uint8_t PIN_I2C_SDA       = 21;
constexpr uint8_t PIN_I2C_SCL       = 22;
constexpr uint32_t I2C_FREQ_HZ     = 400000;  // 400 kHz Fast-mode

// I2C addresses
constexpr uint8_t I2C_ADDR_OLED    = 0x3C;    // SH1106 default
constexpr uint8_t I2C_ADDR_BME280  = 0x76;    // SDO → GND
constexpr uint8_t I2C_ADDR_QMC5883P = 0x2C;   // QMC5883P default
constexpr uint8_t I2C_ADDR_MPU6050 = 0x68;    // AD0 → GND

// ---------------------------------------------------------------------------
//  5-Way Navigation Button (active-low, use INPUT_PULLUP)
// ---------------------------------------------------------------------------
constexpr uint8_t PIN_BTN_UP       = 32;
constexpr uint8_t PIN_BTN_DOWN     = 33;
constexpr uint8_t PIN_BTN_LEFT     = 25;
constexpr uint8_t PIN_BTN_RIGHT    = 26;
constexpr uint8_t PIN_BTN_CENTER   = 27;

// Debounce & long-press timing (ms)
constexpr uint16_t BTN_DEBOUNCE_MS      = 50;
constexpr uint32_t WAKE_HOLD_MS         = 3000;  // wake hold time
constexpr uint16_t BTN_LONG_PRESS_MS    = 3000;  // deep sleep
constexpr uint16_t BTN_DOUBLE_PRESS_MS  = 300;   // double-press window
constexpr uint16_t BTN_REPEAT_DELAY_MS  = 400;   // auto-repeat start
constexpr uint16_t BTN_REPEAT_RATE_MS   = 150;   // auto-repeat interval

// ---------------------------------------------------------------------------
//  Calypso Wind Sensor (UART2) — prepared, not yet connected
// ---------------------------------------------------------------------------
constexpr uint8_t  PIN_WIND_RX     = 16;   // ESP32 RX ← Calypso TX
constexpr uint8_t  PIN_WIND_TX     = 17;   // ESP32 TX → Calypso RX
constexpr uint32_t WIND_BAUD       = 4800; // Calypso NMEA default

// ---------------------------------------------------------------------------
//  Status LED
// ---------------------------------------------------------------------------
constexpr uint8_t PIN_LED          = 2;

// ---------------------------------------------------------------------------
//  WiFi Access Point
// ---------------------------------------------------------------------------
constexpr const char* WIFI_SSID     = "BallisticSentinel";
constexpr const char* WIFI_PASS     = "longrange";   // min 8 chars
constexpr uint16_t    WIFI_PORT     = 80;

// ---------------------------------------------------------------------------
//  Display
// ---------------------------------------------------------------------------
constexpr uint8_t DISPLAY_WIDTH    = 128;
constexpr uint8_t DISPLAY_HEIGHT   = 64;

// ---------------------------------------------------------------------------
//  Application Timing
// ---------------------------------------------------------------------------
constexpr uint16_t DISPLAY_FPS        = 4;      // display refresh rate
constexpr uint16_t ENV_SENSOR_INTERVAL_MS  = 2000;  // BME280 + compass (0.5 Hz)
constexpr uint16_t CANT_SENSOR_INTERVAL_MS = 500;   // MPU6050 cant + compass (2 Hz)
constexpr uint8_t  CANT_CALIB_SAMPLES = 20;   // samples to average for cant calibration

// ---------------------------------------------------------------------------
//  Auto-Dim & Auto-Sleep (motion-based)
// ---------------------------------------------------------------------------
constexpr uint32_t AUTO_DIM_TIMEOUT_MS     = 120000;  // 2min → dim display
constexpr uint32_t AUTO_SLEEP_TIMEOUT_MS   = 600000;  // 10min without motion → deep sleep
constexpr uint8_t  DISPLAY_CONTRAST_FULL   = 255;    // normal brightness
constexpr uint8_t  DISPLAY_CONTRAST_DIM    = 35;     // ~20% of full (~80% reduction)
constexpr float    MOTION_THRESHOLD_MPS2   = 2.0f;   // accel delta in m/s² (~0.43g)
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

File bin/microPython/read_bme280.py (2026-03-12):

"""
Read BME280/BMP280 sensor data on ESP32 WROOM via I2C
Wiring:
  VCC -> 3.3V
  GND -> GND
  SCL -> GPIO 22
  SDA -> GPIO 21
"""

from machine import Pin, I2C
from time import sleep
from bme280 import BME280

# Initialize I2C (default ESP32 pins)
i2c = I2C(0, scl=Pin(22), sda=Pin(21), freq=400000)

# Scan for devices
devices = i2c.scan()
if devices:
    print("I2C devices found:", ["0x{:02X}".format(d) for d in devices])
else:
    print("No I2C devices found! Check wiring.")

# Initialize sensor
sensor = BME280(i2c)
print("Detected:", sensor.chip_name)
print("-" * 40)

# Read and print data every 2 seconds
while True:
    print("Detected:", sensor.chip_name)
    temp, pressure, humidity = sensor.read()

    print("Temperature: {:.1f} °C / {:.1f} °F".format(temp, temp * 9/5 + 32))
    print("Pressure:    {:.2f} hPa".format(pressure))

    if humidity is not None:
        print("Humidity:    {:.1f} %".format(humidity))
    else:
        print("Humidity:    N/A (BMP280)")

    print("-" * 40)
    sleep(2)

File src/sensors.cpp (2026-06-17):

#include "sensors.h"
#include "config.h"

#include <Wire.h>
#include <Adafruit_BME280.h>
#include <Adafruit_MPU6050.h>
#include <Adafruit_Sensor.h>
#include <driver/adc.h>
#include <esp_adc_cal.h>
#include <cmath>

// ── QMC5883P register definitions ─────────────────────────────────────────
namespace qmc5883p {
    constexpr uint8_t REG_CHIP_ID   = 0x00;  // should read 0x80
    constexpr uint8_t REG_DATA      = 0x01;  // 6 bytes: XL XH YL YH ZL ZH
    constexpr uint8_t REG_STATUS    = 0x09;  // bit 0 = DRDY
    constexpr uint8_t REG_CTRL1     = 0x0A;
    constexpr uint8_t REG_CTRL2     = 0x0B;
    constexpr uint8_t REG_SET_RESET = 0x29;

    constexpr uint8_t CHIP_ID_VAL   = 0x80;

    // CTRL1: OSR(7:6) | RNG(5:4) | ODR(3:2) | MODE(1:0)
    //   OSR=00 (512)  RNG=00 (2G)  ODR=11 (200Hz)  MODE=01 (continuous)
    constexpr uint8_t CTRL1_CONT_200HZ = 0x0D;
    //   OSR=00 (512)  RNG=00 (2G)  ODR=01 (10Hz)   MODE=01 (continuous)
    constexpr uint8_t CTRL1_CONT_10HZ  = 0x05;

    static void writeReg(uint8_t reg, uint8_t val) {
        Wire.beginTransmission(cfg::I2C_ADDR_QMC5883P);
        Wire.write(reg);
        Wire.write(val);
        Wire.endTransmission();
    }

    static uint8_t readReg(uint8_t reg) {
        Wire.beginTransmission(cfg::I2C_ADDR_QMC5883P);
        Wire.write(reg);
        Wire.endTransmission(false);
        Wire.requestFrom(cfg::I2C_ADDR_QMC5883P, (uint8_t)1);
        return Wire.available() ? Wire.read() : 0xFF;
    }

    static bool init() {
        // Verify chip ID
        uint8_t id = readReg(REG_CHIP_ID);
        Serial.printf("[sensors] QMC5883P chip ID: 0x%02X (expected 0x%02X)\n", id, CHIP_ID_VAL);
        if (id != CHIP_ID_VAL) return false;

        writeReg(REG_SET_RESET, 0x06);            // recommended SET/RESET
        writeReg(REG_CTRL1, CTRL1_CONT_200HZ);    // continuous, 200Hz, 2G, OSR512
        return true;
    }

    /// Read raw X/Y/Z from the magnetometer.  Returns false if not ready.
    static bool readRawXY(float& x_out, float& y_out) {
        if (!(readReg(REG_STATUS) & 0x01)) return false;

        Wire.beginTransmission(cfg::I2C_ADDR_QMC5883P);
        Wire.write(REG_DATA);
        Wire.endTransmission(false);
        if (Wire.requestFrom(cfg::I2C_ADDR_QMC5883P, (uint8_t)6) != 6) return false;

        int16_t x = (int16_t)(Wire.read() | (Wire.read() << 8));
        int16_t y = (int16_t)(Wire.read() | (Wire.read() << 8));
        Wire.read(); Wire.read();  // Z bytes consumed but unused

        x_out = (float)x;
        y_out = (float)y;
        return true;
    }

    /// Compute heading from calibrated X/Y values.
    static float headingFromCalibratedXY(float raw_x, float raw_y,
                                          float off_x, float off_y,
                                          float scl_x, float scl_y) {
        float cx = (raw_x - off_x) * scl_x;
        float cy = (raw_y - off_y) * scl_y;
        float heading = atan2f(cy, cx) * 180.0f / (float)M_PI;
        if (heading < 0.0f) heading += 360.0f;
        return heading;
    }
} // namespace qmc5883p

// ── Heading circular moving average (sin/cos to handle 0°/360° wrap) ─────
static constexpr int HDG_AVG_N = 20;       // samples in window
static float hdg_sin_buf[HDG_AVG_N];
static float hdg_cos_buf[HDG_AVG_N];
static float hdg_sin_sum = 0.0f;
static float hdg_cos_sum = 0.0f;
static int   hdg_idx     = 0;
static int   hdg_count   = 0;

static float headingSmooth(float deg) {
    float rad = deg * (float)M_PI / 180.0f;
    float s   = sinf(rad);
    float c   = cosf(rad);

    // Subtract the oldest sample being overwritten
    hdg_sin_sum -= hdg_sin_buf[hdg_idx];
    hdg_cos_sum -= hdg_cos_buf[hdg_idx];

    // Store & accumulate
    hdg_sin_buf[hdg_idx] = s;
    hdg_cos_buf[hdg_idx] = c;
    hdg_sin_sum += s;
    hdg_cos_sum += c;

    hdg_idx = (hdg_idx + 1) % HDG_AVG_N;
    if (hdg_count < HDG_AVG_N) hdg_count++;

    float avg = atan2f(hdg_sin_sum, hdg_cos_sum) * 180.0f / (float)M_PI;
    if (avg < 0.0f) avg += 360.0f;
    return avg;
}

// Module-level instances (hidden from header)
static Adafruit_BME280  s_bme;
static Adafruit_MPU6050 s_mpu;
static esp_adc_cal_characteristics_t s_adc_chars;

void Sensors::begin() {
    // BME280
    data_.bme_ok = s_bme.begin(cfg::I2C_ADDR_BME280, &Wire);
    if (data_.bme_ok) {
        // Forced mode: sensor sleeps between on-demand reads (~1 µA idle)
        s_bme.setSampling(
            Adafruit_BME280::MODE_FORCED,
            Adafruit_BME280::SAMPLING_X2,   // temp
            Adafruit_BME280::SAMPLING_X16,  // pressure
            Adafruit_BME280::SAMPLING_X1,   // humidity
            Adafruit_BME280::FILTER_X16,
            Adafruit_BME280::STANDBY_MS_1000
        );
    }

    // QMC5883P compass
    Wire.beginTransmission(cfg::I2C_ADDR_QMC5883P);
    data_.compass_ok = (Wire.endTransmission() == 0) && qmc5883p::init();
    if (data_.compass_ok) {
        // Lower ODR to 10 Hz for power savings (was 200 Hz)
        qmc5883p::writeReg(qmc5883p::REG_CTRL1, qmc5883p::CTRL1_CONT_10HZ);
        Serial.println("[sensors] QMC5883P OK at 0x2C (10 Hz)");
    } else {
        Serial.println("[sensors] QMC5883P not found at 0x2C");
    }

    // MPU6050 (cant / roll)
    data_.mpu_ok = s_mpu.begin(cfg::I2C_ADDR_MPU6050, &Wire);
    if (data_.mpu_ok) {
        s_mpu.setAccelerometerRange(MPU6050_RANGE_2_G);
        s_mpu.setFilterBandwidth(MPU6050_BAND_21_HZ);
    }

    // Battery ADC (GPIO36 / VP — ADC1_CH0)
    adc1_config_width(ADC_WIDTH_BIT_12);
    adc1_config_channel_atten(ADC1_CHANNEL_0, ADC_ATTEN_DB_11);
    esp_adc_cal_value_t cal_type = esp_adc_cal_characterize(
        ADC_UNIT_1, ADC_ATTEN_DB_11, ADC_WIDTH_BIT_12,
        1100,  // default Vref (overridden by eFuse if available)
        &s_adc_chars);
    Serial.printf("[sensors] ADC cal type: %s\n",
        cal_type == ESP_ADC_CAL_VAL_EFUSE_VREF  ? "eFuse Vref" :
        cal_type == ESP_ADC_CAL_VAL_EFUSE_TP    ? "eFuse Two Point" :
                                                  "Default Vref");
    updateBattery();  // take an initial reading
}

void Sensors::update() {
    updateEnvironment();
    updateCant();
}

void Sensors::updateEnvironment() {
    // ── BME280 (forced mode — trigger measurement then read) ──────────────
    if (data_.bme_ok) {
        s_bme.takeForcedMeasurement();
        float temp_c      = s_bme.readTemperature();       // °C
        float press_hpa   = s_bme.readPressure() / 100.0f; // hPa
        float humidity    = s_bme.readHumidity();           // %

        data_.temperature_f = temp_c * 9.0f / 5.0f + 32.0f;
        data_.pressure_inhg = press_hpa * 0.02953f;        // hPa → inHg
        data_.humidity_pct  = humidity;
    }
}
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

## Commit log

2026-03-12 Add initial implementation of ballistic calculator and related components
    - Implement a MicroPython blink program for ESP32.
    - Add constants for physical and atmospheric calculations in `constants.h`.
    - Create drag coefficient tables in `drag_tables.h`.
    - Implement 3D vector mathematics in `vector3d.h`.
    - Set up PlatformIO project configuration in `platformio.ini`.
    - Add a Python script for comparing C++ ballistic engine output against py_ballisticcalc.
2026-03-12 Refactor unit system handling to support individual unit preferences for distance, temperature, and pressure
2026-03-12 Implement cant calibration feature with auto-calibration and web UI support
2026-03-13 Refactor sensor handling to support QMC5883P compass and add sensor view in display
2026-03-13 Update README to enhance power management details and version history
2026-03-14 Add battery monitoring feature with ADC integration and display updates
2026-03-14 feat: add timer feature for live/staged shooting mode in README
2026-03-14 Add unit tests for the C++ ballistic engine
    This commit introduces a comprehensive suite of unit tests for the ballistic engine, covering various aspects such as constants, vector math, PCHIP interpolation, atmosphere modeling, drag modeling, zero-finding, trajectory computation, and corrections for multiple calibers across different conditions and extreme ranges. The tests are structured to validate the functionality and accuracy of the ballistic calculations, ensuring robustness and reliability in the engine's performance.
    [config.h, main.cpp]
2026-03-14 Add float-precision vector and modify RK4 engine for ESP32 optimization
    - Introduced `Vector3f` for single-precision vector operations to optimize inner loops on ESP32 hardware FPU.
    - Updated `CoriolisParams` to include float-precision acceleration calculations.
    - Modified trajectory calculation methods in `engine_rk4.h` to utilize `Vector3f` for velocity and acceleration, while maintaining position in double precision.
    - Enhanced RK45 integration steps to operate in float precision, improving performance on ESP32.
    - Added conditional compilation for double-precision inner loops for debugging and accuracy comparison.
2026-03-14 feat: update button hold timing constants and improve display wake message
2026-03-21 feat: enhance battery voltage measurement with ADC calibration and improved conversion
2026-06-17 feat: add magnetometer calibration with hard and soft iron correction
    [config.h, display.h, main.cpp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]
2026-06-17 added files for PCB and CAD
    [5Axis button cap-Body.step, 5Axis button cap.FCStd, Tikka T1X thumb grip flat-Body.3mf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]
